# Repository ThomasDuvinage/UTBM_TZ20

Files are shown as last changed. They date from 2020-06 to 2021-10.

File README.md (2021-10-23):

# UTBM TZ20 Project

Welcome to the Github repository of our project !  
It consists in designing, building and programming a full portable console allowing the University of Technology of Belfort-Montbeliard (France) staff to control students attendance at some mandatory events.  
This project involves Raspberry Pi programming through Python, 3D printing, and electronics.
This repository contains all documents related to the project.

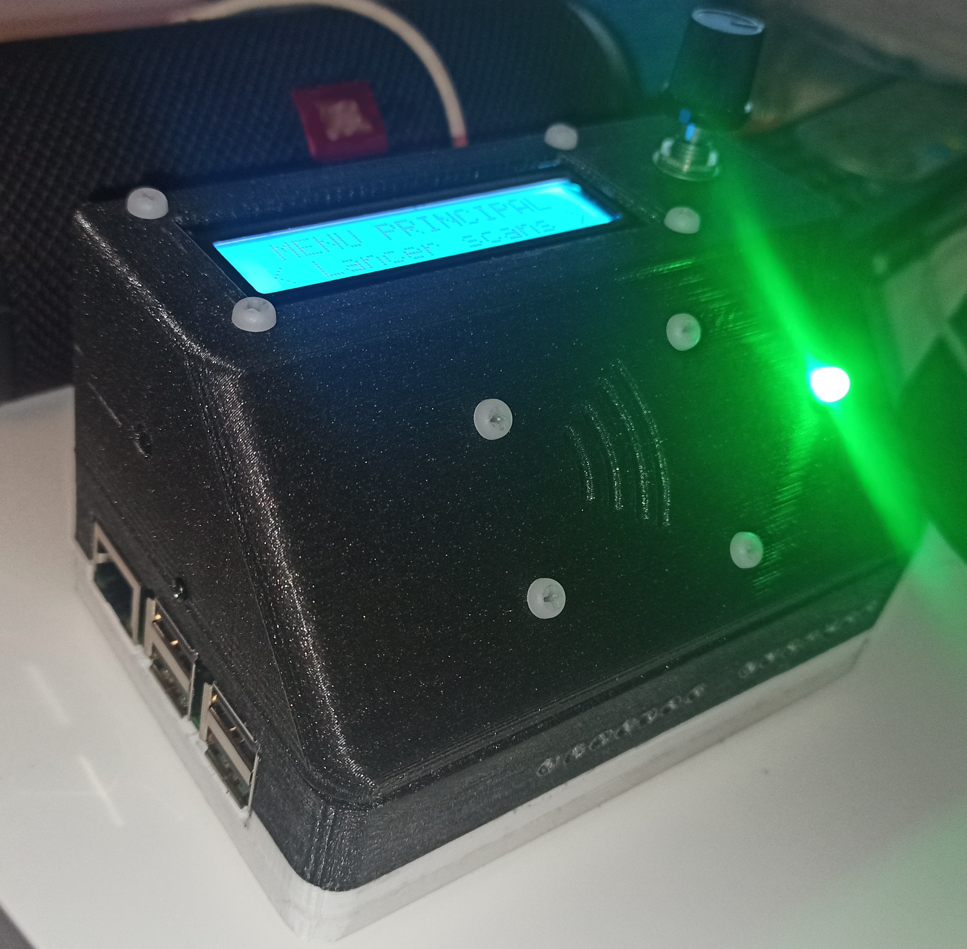
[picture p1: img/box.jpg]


## Useful links : ##

| Description | URL | We used it for : |
|---|---|---|
| RC522 wiring guide | [Click here](https://pimylifeup.com/raspberry-pi-rfid-rc522/) | Wiring RC522 module to the Raspberry Pi. For programming, refer to the line below |
| RC522 python class | [Click here](https://github.com/danjperron/MFRC522-python) | Programming the Raspberry Pi for controlling the RC522 module, especially to read 7 bytes UIDs |
| Git handling from bash terminal | [Click here](https://medium.com/@panjeh/makefile-git-add-commit-push-github-all-in-one-command-9dcf76220f48 )  | Remind us how to handle a git repo from bash terminal |
| Change I2C pins on Raspberry Pi | [Click here](https://raspberrypi.stackexchange.com/questions/88149/change-i2c-pins-on-raspberry-pi) | Opening a second I2C channel on the Raspberry Pi |
| Python class for I2C enabled LCD screens | [Click here](https://www.raspberrypi-spy.co.uk/2015/05/using-an-i2c-enabled-lcd-screen-with-the-raspberry-pi/) | Controlling the 16x2 I2C driven LCD screen through Python |
| Fan controlling from Raspberry Pi | [Click here](https://howchoo.com/g/ote2mjkzzta/control-raspberry-pi-fan-temperature-python) | Wiring and controlling a 5v fan to cool down Raspberry Pi CPU |
| Guide to run python script at Raspi startup | [Click here](https://www.dexterindustries.com/howto/run-a-program-on-your-raspberry-pi-at-startup/#systemd) | Creating a systemd service to run a Python script that reads CPU temp and controls the fan through an hysteresis |
| Guide for using a DS1302 RTC Module with a Raspberry Pi | [Click here](https://github.com/sourceperl/rpi.rtc) | Using an RTC DS1302 module to ensure a non-volatile time management |
| Tutorial about using a config.ini file with Python | [Click here](https://pymotw.com/2/ConfigParser/) | Storing user settings as non-volatile variables |
| Forum about dismounting USB drive from Python | [Click here](https://www.raspberrypi.org/forums/viewtopic.php?t=198250) | Safe ejecting USB keys after importations and exportations

## Hardware (3D printing and electronics) ##
=======
Go to [hardware](hardware/README.md) to see an electronic schematic and our 3D model of the case.

## Installation ##
### By burning TZ20.img to an empty SD card (recommended) ###
>>>>>>> eb0ae4555269eb2e0d8dc44ecf4f938724aca84b

### By cloning this repository ###
Please follow the instructions below to proceed software installation :
1. Make sure wiring is correct (see section *Electronics* above)
2. Download and flash Raspbian or Minibian (command-line only) to an empty SD card (see [here](https://www.raspberrypi.org/documentation/installation/installing-images/))
3. Make sure your default user is named "pi" by opening a terminal (Ctrl + Alt + T) and typing
```
whoami
```
4. Clone this repository to */home/pi* :
```
git clone https://github.com/totordudu/UTBM_TZ20.git
```
5. Enable SPI and I2C interfaces via raspi-config wizard :
```
sudo raspi-config  
```
   * Using your keyboard arrows and Tab key, navigate to **Interfacing Options** and then **I2C**, then confirm
   * Repeat the same operation for **SPI** interface

5.1 Set TimeZone Localisation 
```
sudo raspi-config  
Localisation Option
Change TimeZone
Set to Paris
sudo reboot now
```

6. Run install.sh from the new folder with sudo privileges (you must type your password, by default its *raspberry*) :
```
cd /home/pi/UTBM_TZ20/
sudo chmod +x install.sh
sudo ./install.sh
```
7. Check that *script/main.py* has *-rwxrwxrwx* permissions :
```
ls -l /home/pi/UTBM_TZ20/script/main.py
```
* Otherwise, give those permissions :
    ```
    sudo chmod 777 /home/pi/UTBM_TZ20/script/main.py
    ```

8. Then the script main.py should normally run by typing the following command : 
```
/usr/bin/python /home/pi/UTBM_TZ20/script/main.py
```

9. Restart your raspberry, and *main.py* should automatically start
```
sudo reboot now
```

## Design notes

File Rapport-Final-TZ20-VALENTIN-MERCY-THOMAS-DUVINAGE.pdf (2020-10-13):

# Projet TZ20 Boîtier de contrôle de présence des étudiants

## Rapport final

Etudiants : Valentin Mercy / Thomas Duvinage

Enseignant suiveur : Alexis Flesch

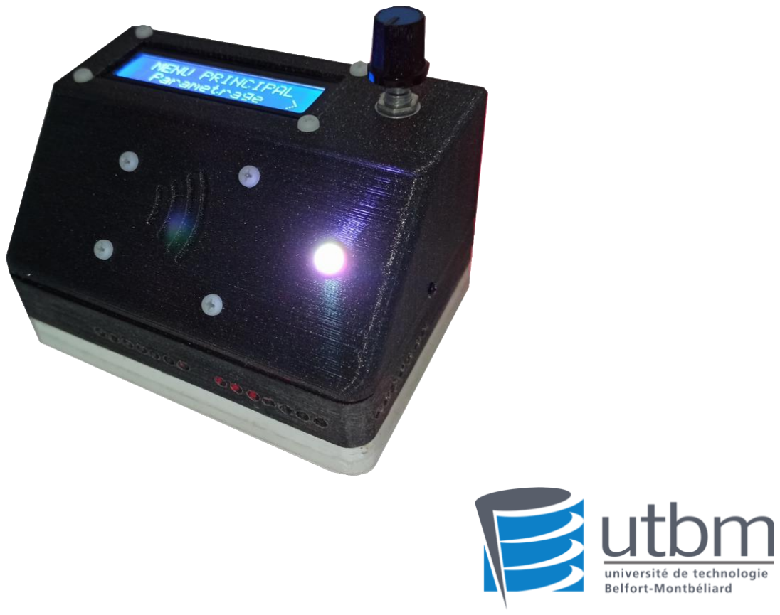
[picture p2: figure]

Valentin Mercy – Thomas Duvinage | Semestre P20 | Page 2/17

Table des matières

Introduction

Ce rapport vient faire suite au rapport intermédiaire rendu au milieu du semestre. Il présentera l’ensemble des travaux réalisés par Thomas Duvinage et Valentin Mercy dans le cadre de l’unité de valeur TZ20 intitulée « Travaux de laboratoire », au printemps 2020, pour le projet de conception et fabrication d’un boîtier de contrôle de présence des étudiants de l’Université de Technologie de Belfort-Montbéliard suivi par M. Alexis Flesch.
Ce rapport est accompagné des documents suivants :
- La présentation utilisée pour la soutenance finale (PDF)
- Le mode d’emploi du boîtier (PDF)
- Le schéma électronique du boîtier (PDF)
- Un modèle de liste des étudiants à importer dans le boîtier (CSV)

Description du projet

Chaque année, plusieurs centaines d’étudiants rentrent à l’Université de Technologie de Belfort-Montbéliard. Un des passages obligatoires pour tous les étudiants de première année est la formation sécurité (il s’agit d’un exemple de ce qui sera dorénavant désigné par le terme « événement ») avant le premier départ en stage. Pour s’assurer que tous les étudiants ont participé à cette formation, l’UTBM a mis en place un système d’émargement informatisé.

Ce système actuel est constitué d’un lecteur RFID¹ USB qui permet aux étudiants de badger avec leur carte étudiante. Celui-ci est relié à un ordinateur portable qui enregistre l’UID (Unique Identifier) de chaque carte dans un fichier CSV²

Après chaque événement, la secrétaire du Tronc Commun UTBM et/ou ses collègues (qui seront dorénavant désignés par le terme « utilisateur ») respectent une certaine procédure :

1) Emport de l’équipement nécessaire (au moins deux appareils : le PC portable (lourd), le lecteur de cartes, et éventuellement un chargeur)
2) Sur le lieu de l’événement : les étudiants sont contraints de rentrer dans l’amphithéâtre un par un, car ils doivent tous se présenter au lecteur de cartes. Un programme exécuté sur le PC portable enregistre un à un les UID des cartes étudiantes. L’arrêt de l’exécution de ce programme met définitivement fin au contrôle de présence, et le matériel est rangé³ .
3) A la fin de l’événement : connexion de l’ordinateur à un réseau wifi et utilisation d’un second programme pour récupérer les logins⁴ en fonction de l’UID de chaque carte.
4) Récupération auprès du service informatique (DSI) du fichier regroupant les informations d’identité des étudiants censés être présents lors de la formation. Avec ce fichier l’utilisateur extrait les noms et prénoms attachés au login. Cela génère deux fichiers : un premier constituant la liste des présents et l’autre la liste des absents.
5) Pour les étudiants qui n’ont pas badgé mais qui ont été signalés présents grâce à l’émargement manuscrit, ils sont retirés manuellement de la liste des absents.

1 RFID = Radio-Frequency Identification (wikipedia.fr, 2020)
2 CSV = Comma Separated Values. Il s’agit d’un fichier texte contenant des chaînes de caractères séparées par des virgules.
3 Ainsi, les étudiants qui se présentent en retard sont listés de façon manuscrite, et retirés un à un de la liste des absents de retour au bureau.
4
Les logins sont des chaînes de caractères courtes qui identifient chaque étudiant de l’UTBM de manière unique.

De plus, en fonction de l’endroit où il est situé, l’utilisateur n’a pas forcément la possibilité de brancher l’ordinateur à une prise électrique. Un autre problème vient de la fiabilité comme nous l’a fait remarquer Madame Cagnon (actuelle secrétaire du Tronc Commun) :
« Nous ne sommes pas sûrs que tous les étudiants aient bien été enregistrés (pas de signal sonore ou de diode lumineuse). Nous devons faire trop de manipulations pour extraire la liste des étudiants. »

Ainsi l’objectif de ce projet est d’automatiser ce processus afin de soulager les utilisateurs et les étudiants, en construisant un boîtier portable et léger intégrant tous les périphériques nécessaires au contrôle de présence. Cela permettra à terme de gagner en efficacité, en temps et de s’affranchir d’éventuelles erreurs de manipulations. Afin de supprimer les files d’attentes (dont la taille excède parfois les 200 étudiants), le boîtier devra pouvoir circuler d’étudiant en étudiant pour un contrôle ultérieur à leur installation dans l’amphithéâtre.

Pour cela le système doit avoir les caractéristiques suivantes :
- Être compact
- Composé d’un seul boîtier portable
- Pas de fils extérieurs
- Être autonome en énergie pour une durée d’au moins 1 heure
- Être rechargeable
- Être simple d’utilisation : limiter la manipulation du boitier au strict nécessaire
- Lire et générer des fichiers compatibles avec Excel
- Respecter le RGPD⁵
- Être capable d’émettre des signaux lumineux et sonore
- Limiter les interactions avec la DSI⁶
- Être inviolable et inextinguible par les étudiants dont on contrôle la présence
- Pouvoir communiquer avec une clé USB (en lecture et en écriture)
- Distinguer les « faux présents » (étudiants qui se présentent alors qu’ils ne sont pas invités à l’événement) des présents
- Être capable de fusionner les résultats d’un contrôle de présence à un autre contrôle réalisé sur un deuxième boîtier identique, dans le cas où l’on souhaiterait procéder à deux contrôles de présence pour un même événement afin, par exemple, de permettre une installation des étudiants plus rapide

Analyse fonctionnelle

Pour exprimer plus clairement le besoin du secrétariat, nous l’avons représenté sur un diagramme bête à cornes :

5 RGPD = Règlement Général sur la Protection des Données 6 DSI = Direction des Services Informatiques (à l’UTBM)

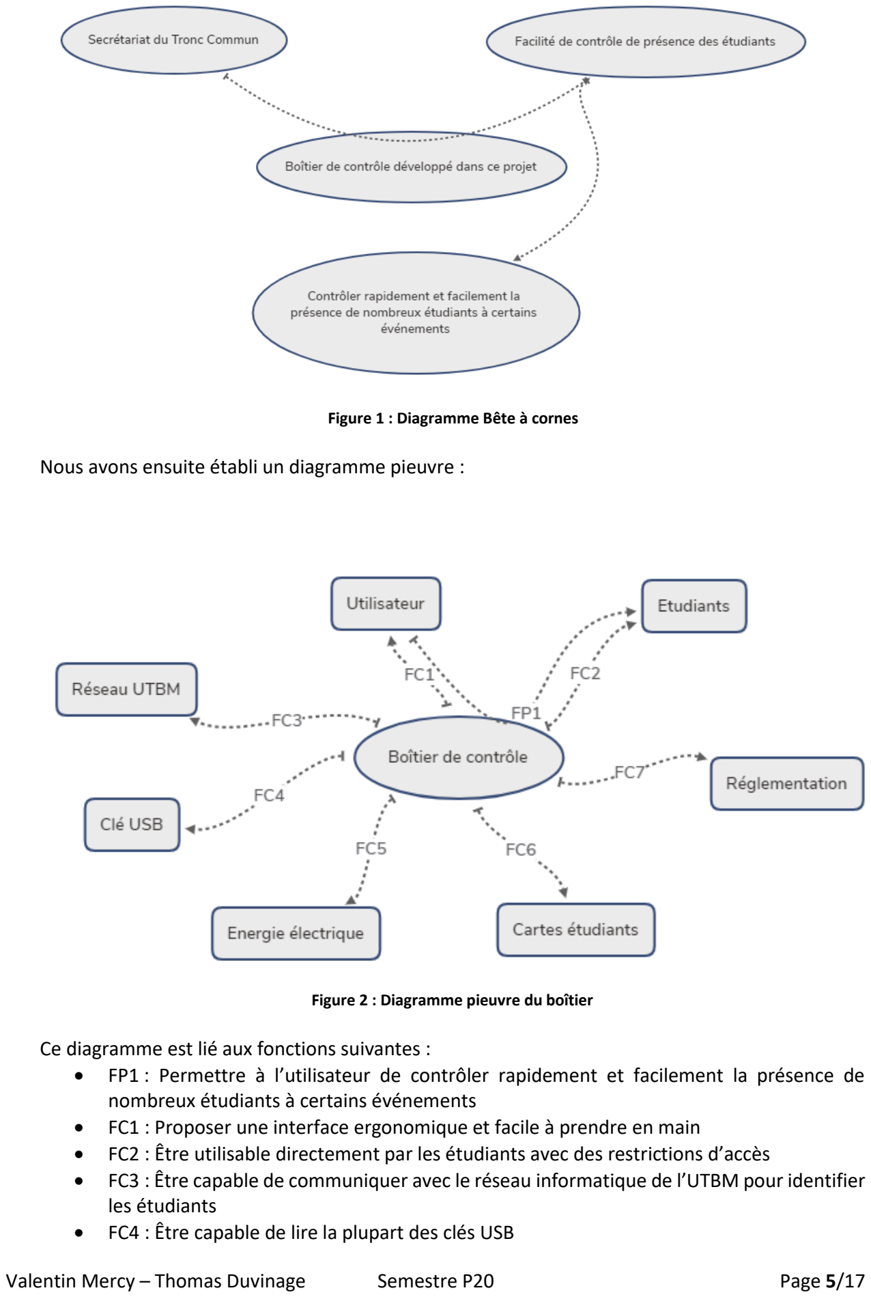
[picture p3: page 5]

Nous avons ensuite établi un diagramme pieuvre :

Figure 2 : Diagramme pieuvre du boîtier

Ce diagramme est lié aux fonctions suivantes :
- FP1 : Permettre à l’utilisateur de contrôler rapidement et facilement la présence de nombreux étudiants à certains événements
- FC1 : Proposer une interface ergonomique et facile à prendre en main
- FC2 : Être utilisable directement par les étudiants avec des restrictions d’accès
- FC3 : Être capable de communiquer avec le réseau informatique de l’UTBM pour identifier les étudiants
- FC4 : Être capable de lire la plupart des clés USB

Figure 1 : Diagramme Bête à cornes

- FC5 : Être autonome en énergie pendant la durée d’un contrôle (au moins une demi-heure)
- FC6 : Être capable de lire les cartes étudiants UTBM
- FC7 : Respecter la réglementation (respect de la vie privée)

Les composants nécessaires

Pour la réalisation de ce projet nous avons besoin de quelques composants électroniques classiques (la plupart étant disponibles préconditionnés en modules) ainsi que de certains éléments de fixation. Vous trouverez dans le tableau ci-dessous la description de l’ensemble des composants ainsi qu’un budget matériel estimatif pour le projet. Il faut également prévoir quelques consommables habituels, spécifiés en rouge dans le tableau.

Liste du matériel - Prix total HT : 86 €
Désignation | Catégorie | Référence | Caractéristiques | Qté | Exemple
URL | Prix HT | Fournisseur | Prix total HT
Raspberry Pi | Eléctronique | 3B+ | Modèle 3B+ ou 4 | 1 | Cliquer ici (https://www.gotronic.fr/art-carte-raspberry-pi-3-b-27826.htm) | 36,63 € | Gotronic | 36,63 €
Ventilateur | Eléctronique | | 30*30*10mm – 5V | 1 | Cliquer ici (https://www.gotronic.fr/art-ventilateur-compatible-pi-29290.htm) | 8,29 € | Gotronic | 8,29 €
Ecran LCD + interface I2C | Eléctronique | | 16x2 – avec module I2C | 1 | Cliquer ici (https://www.gotronic.fr/art-afficheur-lcd-i2c-2x16-caracteres-25650.htm) | 8,25 € | Gotronic | 8,25 €
Alimentation CC | Eléctronique | PS910 | 9V 1A | 1 | Cliquer ici (https://www.gotronic.fr/art-adaptateur-coude-ps910-29061.htm) | 7,17 € | Gotronic | 7,17 €
Level shifter | Eléctronique | CYT1076 | Prix pour pack de 10 pièces – 1 suffit | 1 | Cliquer ici (https://www.amazon.fr/Gebildet-3-3V-5V-Channels-Converter-Bi-Directional/dp/B07RY15XMJ?__mk_fr_FR=Å%20MÅŽÕÑ) | 5,99 € | Amazon | 5,99 €
Powerbank | Eléctronique | U = 5V, I>=1A | à modifier pour souder deux fils en sortie (pas la place pour une prise) | 1 | | | | 5,00 €
Module régulateur de tension | Eléctronique | DRF0571 | Tension entrée : 1.25V – 30V | Sortie : 5V | 1 | Cliquer ici (https://www.gotronic.fr/art-regulateur-5-vcc-dfr0571-29558.htm) | 3,29 € | Gotronic | 3,29 €
Connecteur GPIO femelle à souder | Consommable | | 40 pins (2*20) | 1 | Cliquer ici (https://www.gotronic.fr/art-connecteur-2x20-broches-he40rpi-28118.htm) | 2,58 € | Gotronic | 2,58 €
Buzzer piezoelectrique | Eléctronique | THDZ | | 1 | Cliquer ici (https://www.gotronic.fr/art-buzzer-sv3-3828.htm) | 2,46 € | Gotronic | 2,46 €

Encodeur
rotatif | Eléctronique | KY40 | Bouton intégré | 1

Cliquer
ici (https://www.gotronic.fr/art-module-encodeur-rotatif-gt055-28502.htm)

1,83

€ | Gotronic | 1,83 €
Module RTC | Eléctronique | Module à base de DS1302 | Prix pour pack de 5 pièces – 1 suffit | 1 | Cliquer ici (https://www.amazon.fr/SODIAL-DS1302-Module-Horloge-bouton/dp/B00PXVAKJW?__mk_fr_FR=ÅMÅŽÕÑ) | 1,39 € | Amazon | 1,39 €
Transistor NPN | Eléctronique | 2N2222 | hauteur >=6mm | 1 | Cliquer ici (https://www.gotronic.fr/art-transistor-2n2222a-to92-1539.htm) | 0,25 € | Gotronic | 0,25 €
Fixation LED | Mécanique | | pour LED 5mm | 1 | Cliquer ici (https://www.gotronic.fr/art-clip-5-mm-clip5-2140.htm) | 0,17 € | Gotronic | 0,17 €
Bouton 6x6mm | Eléctronique | KRS0610 | hauteur 7mm | 1 | Cliquer ici (https://www.gotronic.fr/art-bp-subminiature-krs0610-4269.htm) | 0,25 € | Gotronic | 0,25 €
Led rouge | Eléctronique | | 3mm | 1 | Cliquer ici (https://www.gotronic.fr/art-led-3-mm-rouge-l934hd-2058.htm) | 0,13 € | Gotronic | 0,13 €
IRF7319 | Eléctronique | IRF7319 | Composant à monter en surface | 1 | Cliquer ici (https://www.digikey.com/product-detail/en/infineon-technologies/IRF7319TRPBF/IRF7319PBFCT-ND/827930) | 0,83 € | Digikey | 0,83 €
MCP3001 | Eléctronique | MCP3001 | Convertisseur analogique numérique | 1 | Cliquer ici (https://www.digikey.fr/product-detail/en/microchip-technology/MCP3001-I-P/MCP3001-I-P-ND/319407) | 1,51 € | Digikey | 1,51 €
Entretoises taraudées | Mécanique | | M3*6+6 – Nylon de préférence (pour fixations isolées) | 8 | | | | 0,00 €
Vis | Mécanique | | M3*6 | 14 | | | | 0,00 €
Résistances 1/4W | Consommable | | 1*680 R, 2*200 R,1*250 R, 1*500 R, 2*300K | 5 | | | | 0,00 €
Fil électrique souple, multibrin, diam 0,3 | Consommable | 30AWG | Rouge – Noir – Bleu – Vert – Jaune | 5 | | | | 0,00 €
PCB vierge | Consommable | | Carré de 12mm de côté (pour la partie commande du ventilateur) | 1 | | | | 0,00 €

Tableau 1 : Liste du matériel électronique nécessaires pour la réalisation du boitier

L’élément le plus cher utilisé dans le projet est une carte Raspberry Pi 3 modèle B+. Il s’agit d’un nano-ordinateur très performant, de plus en plus utilisé en électronique pour ses ports GPIO⁷ qui

7 GPIO = General Purpose Input Output permettent de communiquer avec une multitude de composants. Ce nano-ordinateur est particulièrement adapté à ce projet car ce dernier implique de la gestion de fichiers, une connexion à Internet filaire, et une communication avec clé USB. Or la Raspberry Pi 3 embarque déjà des ports USB, une prise Ethernet et, en tant que nano-ordinateur exécutant un système d’exploitation basé sur Linux, a déjà tout ce qu’il faut pour manipuler simplement des fichiers en lignes de commandes.
Nous aurions pu nous tourner vers une solution moins gourmande en énergie (type Arduino) mais il aurait alors fallu rajouter tous les modules nécessaires à nos communications. Finalement, le projet serait donc revenu bien plus cher et les performances auraient été très réduites (l’Arduino n’étant pas capable, par exemple, de gérer plusieurs processus en simultané, ce que la Raspberry sait faire).

En plus des composants électroniques, un accès à un FabLab ou un atelier est recommandé, dans la mesure où la réalisation du boîtier nécessite un accès aux machines suivantes :

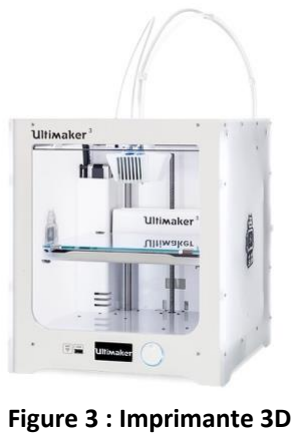
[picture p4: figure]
Figure 3 : Imprimante 3D

- Imprimante 3D (min 100x100x150mm de volume
imprimable)

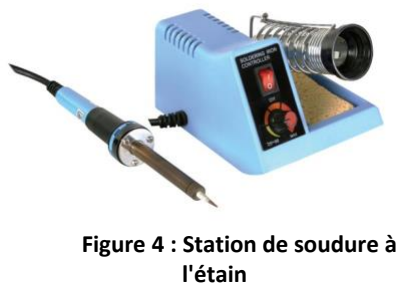
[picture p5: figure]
Figure 4 : Station de soudure à l'étain

- Fer à souder

Schéma électronique

Voici le schéma électronique final du boîtier (celui-ci a été réalisé avec le logiciel Autodesk Eagle) :

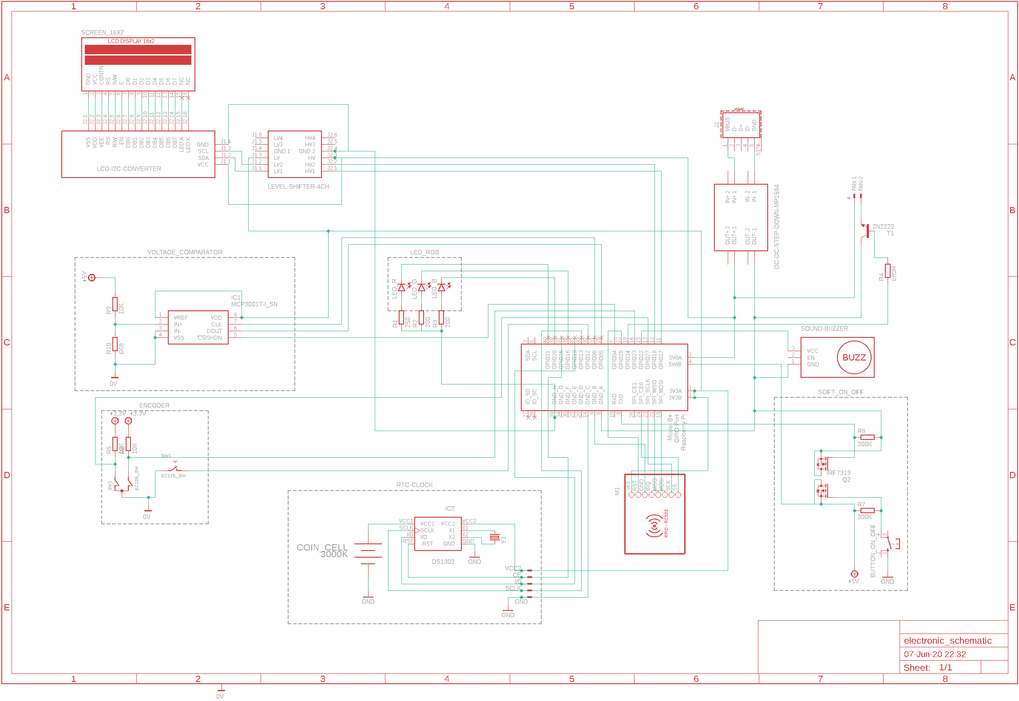
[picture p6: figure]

Figure 5 : Schéma électronique du boîtier

Cette version finale contient les ajouts liés à la détection du niveau de batterie et au circuit de gestion de l’alimentation qui n’étaient pas présents dans le rapport intermédiaire.

Modélisation et impression 3D du boîtier

Une étape importante du projet qui n’a pas été mentionnée dans le rapport intermédiaire a été la modélisation du boîtier. Celle-ci a été faite avec le logiciel Fusion 360. Voici le résultat de notre modélisation (téléchargeable sur notre dépôt Git (https://github.com/totordudu/UTBM_TZ20) ou sur GrabCad) (https://grabcad.com/library/presence-box-1) :

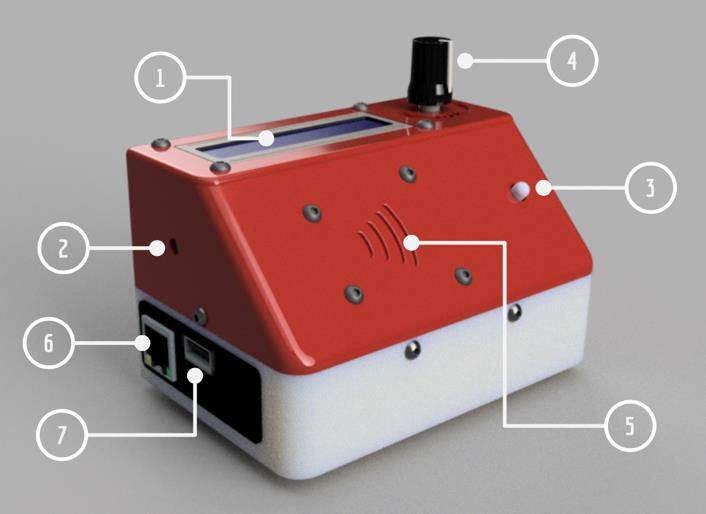
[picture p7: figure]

1. Écran
2. Buzzer
3. LED d’état
4. Sélecteur de menu
5. Zone de scan
6. Port Ethernet
7. Prise USB
8. LED d’allumage
9. Prise d’alimentation
10. Bouton D

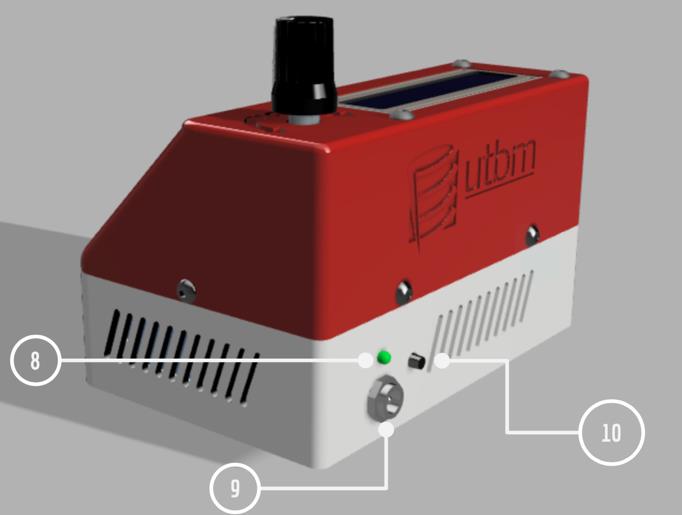
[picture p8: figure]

Le boitier a été imprimé en 3D sur nos machines personnelles.

Organisation de la programmation

L’ensemble du code source qui permet au boîtier de fonctionner a été écrit en langage Python, version 2.7. Il s’agit de la version préinstallée sur Raspbian (principal système d’exploitation utilisé pour les Raspberry Pi). Une partie non-négligeable des connaissances qui nous ont permis d’écrire ce code source (arbres, fonctions récursives) provient de l’UV LO21 de l’UTBM. Afin de se conformer aux bonnes pratiques liées à l’écriture de code, nous avons décidé d’écrire l’ensemble du code en anglais.

Notre dépôt Git

Figure 6 : Modélisation du boitier

Conscients de la quantité de code à fournir (qui, bien qu’optimisée, s’élève finalement à plus de 2000 lignes) et afin d’appréhender la partie programmation informatique du projet dans les meilleures conditions, nous avons créé un dépôt Git sur GitHub. Git est un gestionnaire de versions de code. Un dépôt Git est un dossier contenant principalement du code, stocké sur un serveur, auquel chaque utilisateur authentifié (possédant un compte associé au projet) peut contribuer. Chaque développeur peut alors cloner ce git localement, y apporter les modifications qu’il souhaite, puis procéder à leur indexation (git commit) avant de les publier (git push).
Notre dépôt Git est hébergé à l’URL suivant : https://github.com/totordudu/UTBM_TZ20.
Nous avons également utilisé les fonctionnalités Issues et Project proposées par GitHub, pour notre organisation personnelle :

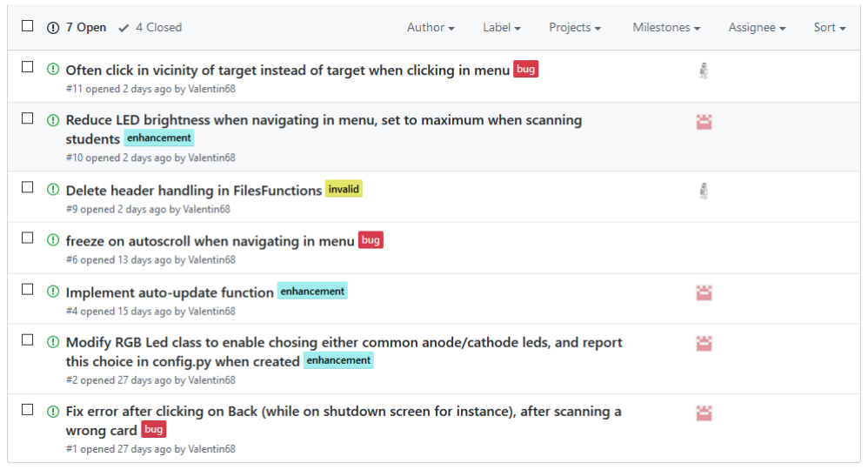
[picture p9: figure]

Depuis le rapport intermédiaire, l’ensemble des Issues importantes ont été traitées. D’autres, moins importantes ou qui auraient nécessité des modifications trop importantes au niveau du code ou de l’électroniques, ont été abandonnées.

Figure 7 : Section "Issues" de notre dépôt Git (au 26/04/2020)

Gestion des fichiers de listes

Pour une meilleure compréhension des différentes opérations de traitement des données (cartes, étudiants, contrôles) réalisées par le boitier, voici un algorigramme :

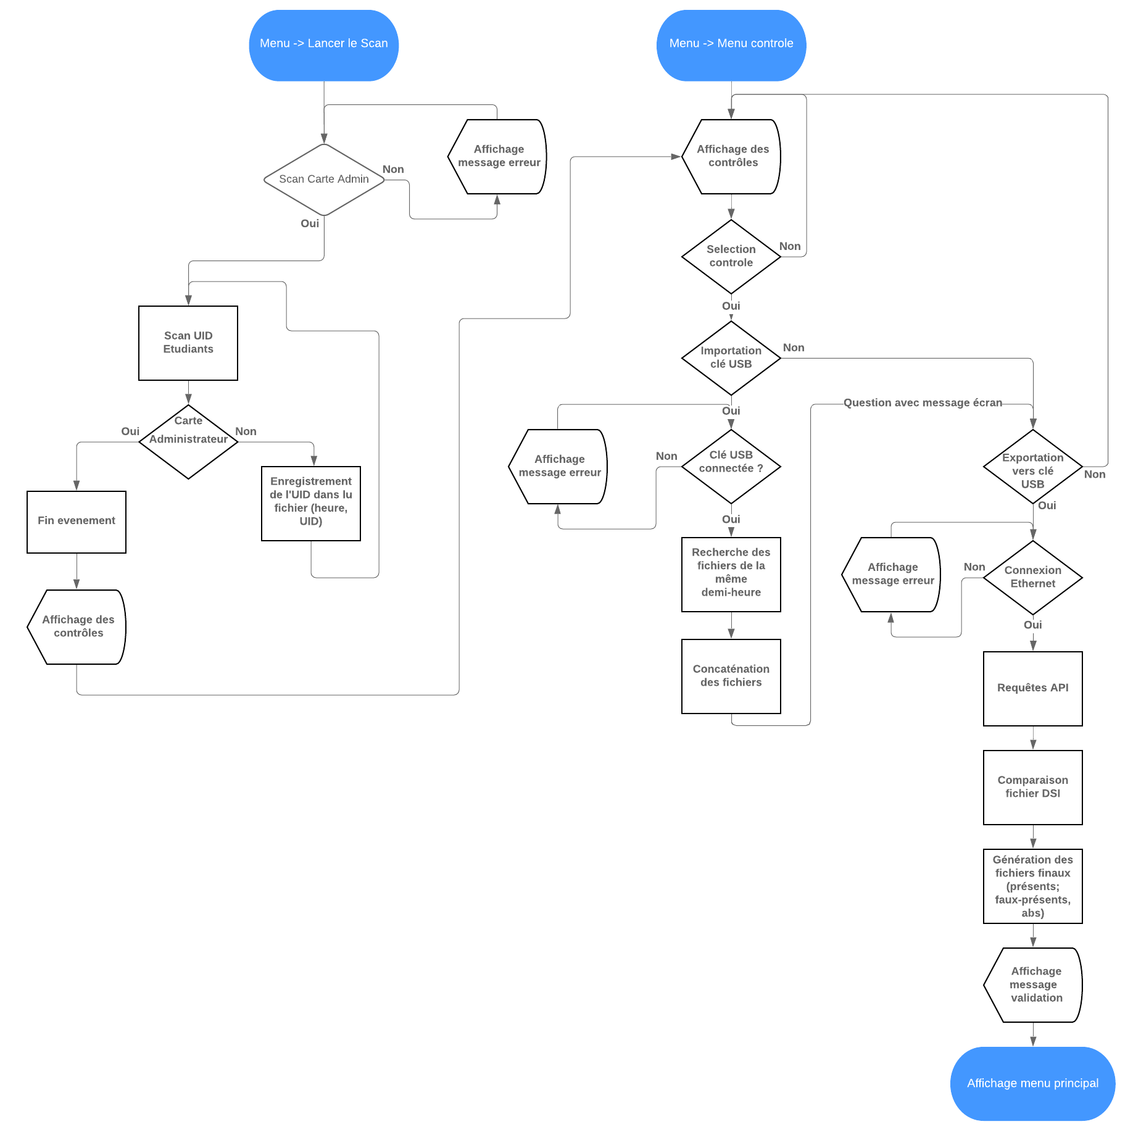
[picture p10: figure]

Librairies utilisées

Plusieurs librairies Python ont été utilisées dans ce projet, toutes ont été trouvées sur GitHub :
- lcd_lib nous permet de gérer l’affichage d’informations sur l’écran LCD via l’interface I2C
- pyRPiRTC nous permet de gérer l’horloge externe (RTC⁸
) en lecture et écriture
- treelib nous permet d’accéder à la structure informatique de l’arbre n-aire dans le cadre de notre menu (voir la partie Chemin utilisateur)

8 RTC = Real Time Clock

Figure 8 : Algorigramme de la gestion des fichiers telle qu’implémentée dans le boitier

- GPIO est une librairie spécifique à Raspbian, permettant de gérer les ports GPIO mentionnés précédemment (entrées/sorties)
- MFRC522 nous permet de communiquer avec le module RC522 (module RFID permettant de scanner les cartes étudiantes)
- datetime nous permet d’accéder à la structure informatique éponyme, qui permet la gestion des ensembles date + heure
- subprocess nous permet de déclencher des sous-processus
- os nous permet de faire appel à des commandes système (normalement saisies dans le terminal)
- signal nous permet de capturer des signaux système (dans notre cas, SIGINT pour une interruption par Ctrl+C) pour les dérouter vers des fonctions appelées traitants (handler en anglais)
- requests nous permet d’envoyer des requêtes vers google pour tester la connexion du boîtier à internet
- ConfigParser nous permet de lire et de modifier le fichier de configuration contenant les paramètres du boîtier, pour les garder en mémoire permanente
- sys nous permet d’utiliser la commande exit() pour mettre fin à l’exécution du programme
- pyudev et psutil nous permettent de détecter le branchement d’une clé USB

Nous avons nous-mêmes codé plusieurs classes Python pour gérer certains éléments propres au boîtier :
- buzzer nous permet de jouer des sons prédéfinis (que nous avons nous-mêmes créés) selon la situation dans laquelle se trouve l’utilisateur
- rgb_led nous permet d’afficher les 7 couleurs avec la LED RGB⁹
, qui vient en complément
de l’écran pour guider l’utilisateur dans le menu et les fonctions auxquelles ce dernier lui permet d’accéder
- rotary_encoder permet de gérer l’encodeur rotatif monté en façade supérieur du boîtier, seule entrée de l’IHM¹⁰ mise en place sur le boîtier, à la fois en rotation et au clic.

Chemin utilisateur

Lors de la programmation d’un boîtier dont l’utilisation doit être simplifiée au maximum tout en assurant un maximum de tâches prédéfinies, il est important de bien réfléchir au chemin utilisateur : l’accessibilité aux différentes fonctions doit être épurée, claire et organisée. Pour ce faire, nous avons imaginé un menu sous forme d’arbre. L’arbre est une structure de données très employée en informatique dès qu’il est utile de hiérarchiser des données sous une arborescence. On parle d’arbre binaire (ou Btree) lorsque chaque nœud a 2 fils au plus, ou d’arbre n-aire dans le cas contraire.

9 RGB = Red Green Blue, appliqué à une LED cela signifie qu’elle peut afficher n’importe quelle couleur par synthèse additive de la lumière
10 IHM = Interface Homme/Machine

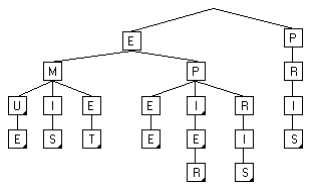
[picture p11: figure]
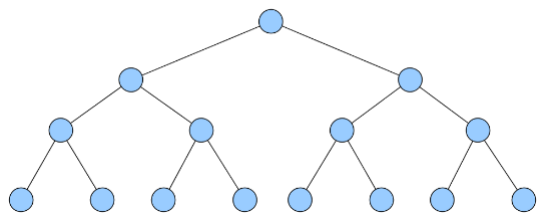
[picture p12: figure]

Dans le cadre de notre menu, nous avons donc choisi d’employer la structure de l’arbre n-aire, prévoyant qu’une entrée de menu permettrait d’accéder à plus de 2 sous-menus. Nous avons essayé d’optimiser ce menu afin de mettre en avant les fonctions qui seront les plus utilisées. Voici l’arbre simplifié de notre menu (l’arbre complet, lui, contient les chaines de caractères à afficher sur l’écran pendant la navigation, la couleur à afficher sur la LED en façade -ici représentée par la couleur du fond du nœud- pour chaque sous-menu ainsi que le nom de la fonction terminale à appeler pour chaque feuille¹¹) :

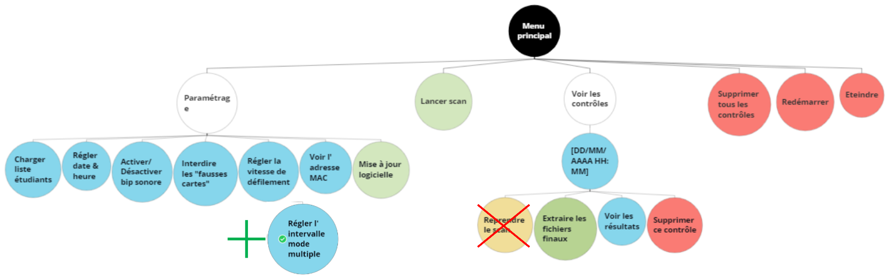
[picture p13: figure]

Depuis le rapport intermédiaire, nous avons supprimé la fonction « Reprendre le scan » accessible depuis le sous-menu « voir les contrôles » car elle est superflue : nous comptions l’implémenter pour permettre à l’administrateur de relancer un scan en cas d’interruption par manque de batterie par exemple. Toutefois, il lui suffirait dans ce cas de lancer le deuxième scan normalement, puis de procéder à une extraction en mode « boitiers multiples » avec fusion pour obtenir de résultat global. Aussi, nous avons ajouté la fonction « Régler l’intervalle du mode multiple » qui permet d’ajuster l’intervalle de temps maximum dans lequel deux contrôles (l’un sur le boîtier, l’autre déjà extrait sur la clé) seront considérés comme similaires et sujets à une fusion des résultats. Pour mieux comprendre, lisez la section Extraction et visualisation des résultats.

Précisions supplémentaires

- Un paramètre « Interdire les fausses cartes » apparaît dans l’arbre du menu. Celui-ci permet d’activer ou de désactiver une restriction lors de la phase de scans : lorsqu’elle est

11 Une feuille est un nœud de l’arbre qui n’a aucun fils (dans notre cas, cela correspond aux fonctions, que l’on désigne ici comme fonctions « terminales », auquel notre menu permet d’accéder)

Figure 10 : Exemple d'arbre binaire

Figure 9 : Exemple d'arbre n-aire

Figure 11 : Arbre simplifié du menu de navigation du boîtier activée, cette restriction empêche les étudiants de scanner d’autres objets compatibles RFID que leur carte étudiante. Toutefois, comme cette restriction se base sur le format des UID de cartes (format spécifique au fournisseur de l’UTBM), nous avons pensé qu’il pourrait être utile de permettre à l’utilisateur de lever cette restriction en cas de changement de fournisseur par exemple, ou bien s’il souhaite contrôler un jour la présence de personnes ne possédant pas de carte UTBM.
- Un paramètre « Voir l’adresse MAC » permet à l’utilisateur de connaître facilement l’adresse physique de la Raspberry. En effet, il est important de la connaître puisqu’elle doit être ajoutée par la DSI à la liste blanche des équipements autorisés à accéder au réseau filaire. Cette autorisation lui sera indispensable pour pouvoir utiliser l’API fournie par la DSI permettant de connaître les propriétaires des cartes étudiantes.
- Un paramètre « mise à jour logicielle » permet à l’utilisateur de mettre à jour notre programme automatiquement. Cela sera utile dans le futur si des bugs que nous n’aurions pas anticipés surviennent après un certain nombre d’utilisations
- Dans la section « Voir contrôles », les différents contrôles auxquels il est possible d’accéder sont identifiés par leur date de création au format DD/MM/AAAA HH:MM.
- En dernière position de chaque sous-menu, une option « RETOUR » permet de remonter au niveau supérieur.

Finalisation du projet

Cette partie présente les étapes de finalisation du projet qui ont été mises en œuvre depuis la rédaction du rapport intermédiaire.

Circuit de gestion de l’alimentation

Le principal élément manquant du schéma électronique publié dans notre rapport intermédiaire était la gestion de la batterie. En effet, nous avions soulevé le problème de la gestion de la batterie en faisant l’expérience d’alimenter la Raspberry Pi en la raccordant directement à la sortie de la batterie. Nous avions alors observé un gros défaut, qui constitue non seulement un trouble pouvant endommager la Raspberry sur le long terme, mais également une entrave à l’ergonomie d’utilisation attendue pour ce boitier : la Raspberry étant toujours alimentée (même si éteinte au niveau logiciel), celle-ci consomme et décharge la batterie jusqu’à son déchargement complet. Pendant ce déchargement, nous avions alors observé un fonctionnement indésirable : la Raspberry tente de s’allumer, puis est coupée en séquence de boot à cause de la chute de tension occasionnée par le démarrage, puis la tension revient à la normale, la Raspberry se rallume, et le cycle recommence jusqu’à épuisement de la batterie.
Nous rappelons par ailleurs qu’en aucun cas la Raspberry ne doit pouvoir être éteinte autrement que par notre programme : les étudiants ne doivent pas pouvoir éteindre le boitier pendant qu’ils scannent leurs cartes, seul l’administrateur peut le décider. C’est pourquoi nous avons intégré le bouton « D » (comme démarrage) dans notre boitier, voir figure 4. (https://github.com/totordudu/UTBM_TZ20)
Nous avons alors établi une liste des fonctions que devrait remplir notre circuit :
- Détection du niveau de batterie et, si sa tension devient insuffisante pour alimenter la Raspberry de manière stable, on lui envoie un signal d’extinction (pour éviter une extinction à chaud, mauvaise pour la carte)
- Coupure de l'alimentation de la Raspberry lorsqu'elle passe en mode "shutdown" (dont l'origine peut être soit le point ci-dessus, soit une extinction volontaire) : il faut donc laisser à la Raspberry le temps de s'éteindre avant d'ouvrir le circuit qui l'alimente
- Réarmement de l'alimentation de la Raspberry par appui sur bouton poussoir. Ce bouton ne doit avoir d'effet que lorsque l'alimentation est coupée et doit alors la rétablir, mais il ne doit pas la couper s'il est actionné et que la Raspberry est alimentée (fonctionnement en sens unique).
- Par ailleurs, le rechargement de la batterie (et donc dépassement du seuil de tension cité plus haut) ne doit pas rallumer la Raspberry, qui ne doit l’être que par un appui sur le bouton D
- Lorsque l'alimentation de la Raspberry est coupée, le circuit lui-même ne doit presque rien consommer (pour éviter d'avoir à recharger la batterie trop souvent)

Après plusieurs recherches infructueuses, nous avons finalement trouvé le circuit suivant (othermod, 2016) appelé Soft On/Off circuit :
Ce circuit fonctionne à partir d’un composant nommé IRF7319 qui n’est autre qu’un assemblage de deux transistors MOSFET, l’un à canal P et l’autre à canal N.
Le transistor à canal P est passant lorsque sa grille (gate) est reliée à la masse, donc lorsqu’on appuie sur le bouton D (Momentary Power Switch). Le second MOSFET, à canal N, permet de maintenir cet état passant : ce dernier n’est passant que lorsque sa grille est à l’état haut, ce qui est le cas lorsque la Raspberry est allumée puisque TXD vaut alors 1. La Raspberry est donc alimentée de manière stable. La seule manière de couper cette alimentation est que TXD passe à l’état bas, ce qui arrive évidemment lorsque la Raspberry est en mode « shutdown » (éteinte logiciellement).

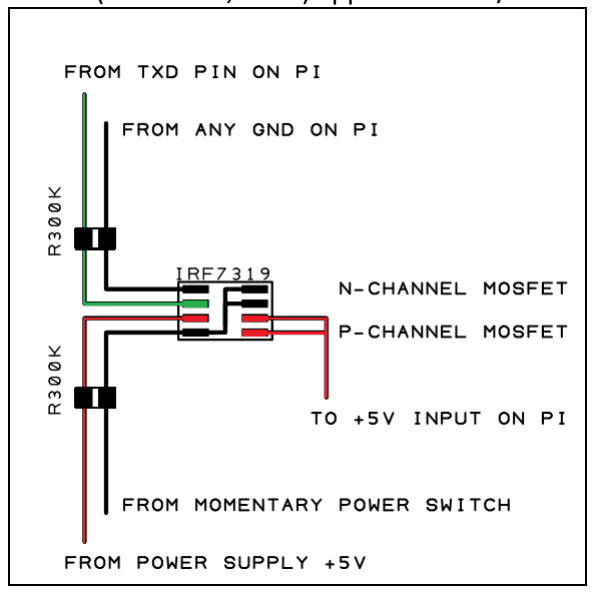
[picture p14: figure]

Ce circuit règle donc une bonne partie du problème, mais il reste la tension de la batterie à gérer : on doit être capables de la lire et de détecter qu’elle passe en dessous d’un certain seuil. La Raspberry Pi ne disposant pas de convertisseur Analogique/Numérique (ADC), nous avons utilisé l’ADC MCP3001 de la très réputée famille des MCP300x et l’avons associé à un pont diviseur dont nous avons judicieusement calculé les valeurs de résistances :
Puisqu’on s’attend à lire une tension maximum de 5v, et qu’on doit retrouver en sortie du pont diviseur une tension de 3v (on garde une marge de sécurité de 0.3v par rapport aux 3.3v de la Raspberry), cela nous donne l’équation suivante (du pont diviseur sans charge avec R1 valant arbitrairement 10K) :
S =

R1
R1+R2

∗ E 3 = 5 ∗

10000
x+10000

=> x ≅ 6K8

Finalement, nous avons donc le circuit de contrôle de tension suivant :

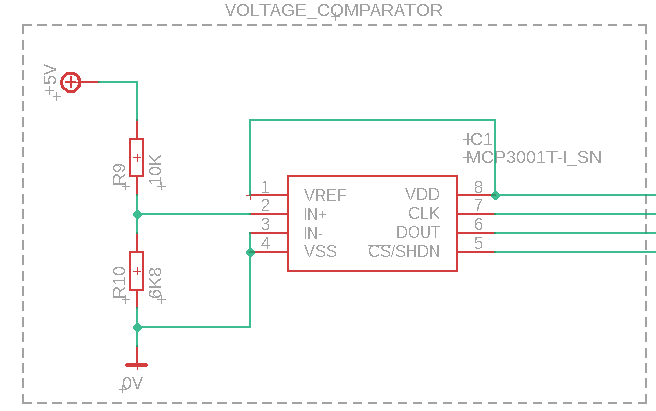
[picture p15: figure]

Figure 12 : Circuit de contrôle de la tension fournie par la batterie

Il nous suffit alors de créer un service sur la Raspberry dont la seule activité sera de lire régulièrement la tension fournie par la batterie, et de déclencher une extinction par sudo shutdown now si cette tension est inférieure à un seuil critique à déterminer.
Ce service (battery.service) et le code Python associé (external_devices/read_voltage.py) sont à retrouver dans le dépôt Git.

Extraction et visualisation des résultats

Concernant l’extraction des fichiers relatifs à un contrôle, nous avons suivi la figure 6 établie pour le rapport intermédiaire au détail près que nous laissons finalement le choix à l’administrateur de rentrer en mode « boitier unique » ou « boitier multiple » suivant qu’il veuille ou non réaliser une fusion par rapport à une extraction précédemment effectuée, dont les résultats sont sur une clé USB branchée à la Raspberry.

Conclusion

Pour conclure, nous sommes très satisfaits du boîtier que nous avons conçu. Nous pensons qu’il répond à tous les critères établis par le secrétariat du Tronc Communs, et attendons leurs premiers tests pour en avoir la confirmation. Mener un tel projet dans une période de confinement n’a pas été chose facile, mais en nous organisant correctement pour travailler efficacement à distance nous avons pu mener le projet à son aboutissement. Celui-ci nous a fait appel à nos connaissances à la fois en mécanique, en électronique et en informatique. Il nous a permis de s’échanger des connaissances et des compétences souvent complémentaires au sein du binôme.

Bibliographie

goobering. 2016. Measuring voltage and current of battery. raspberrypi.stackexchange. [En ligne]
6 | Juillet | 2016. | [Citation | : | 3 | Juin | 2020.]
https://raspberrypi.stackexchange.com/questions/50870/measuring-voltage-and-current-of-battery. othermod. 2016. Raspberry Pi Simple Soft On/Off Circuit. othermod.com. [En ligne] 13 Juillet 2016. [Citation : 03 Juin 2020.] https://othermod.com/raspberry-pi-soft-onoff-circuit/.
wikipedia.fr. 2020. Radio-identification. Wikipedia. [En ligne] 7 avril 2020. [Citation : 20 avril 2020.] https://fr.wikipedia.org/wiki/Radio-identification.

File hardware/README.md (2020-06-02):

## Hardware

### 3D files

To design this box, we used Fusion 360. All the 3D files needed to build this box are available in 3D_prints folder.

All the conception of the box is available on GrabCad at https://grabcad.com/library/presence-box-1

Here are the rendering images of the conception. 

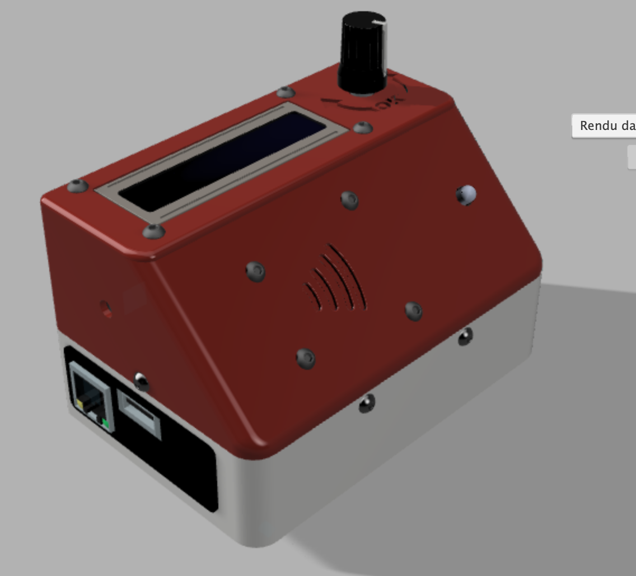
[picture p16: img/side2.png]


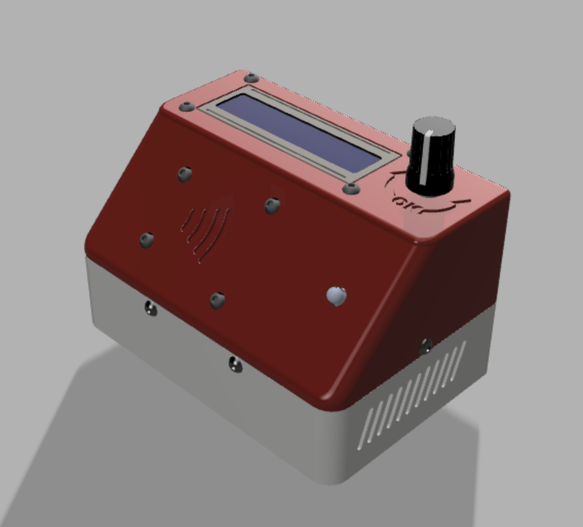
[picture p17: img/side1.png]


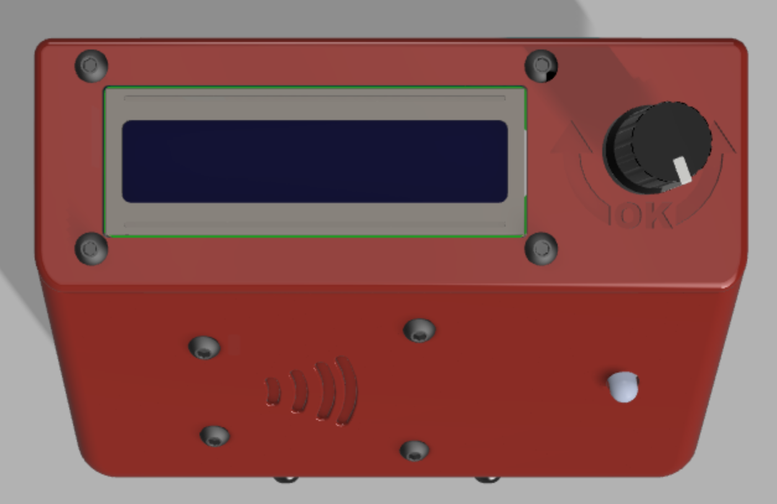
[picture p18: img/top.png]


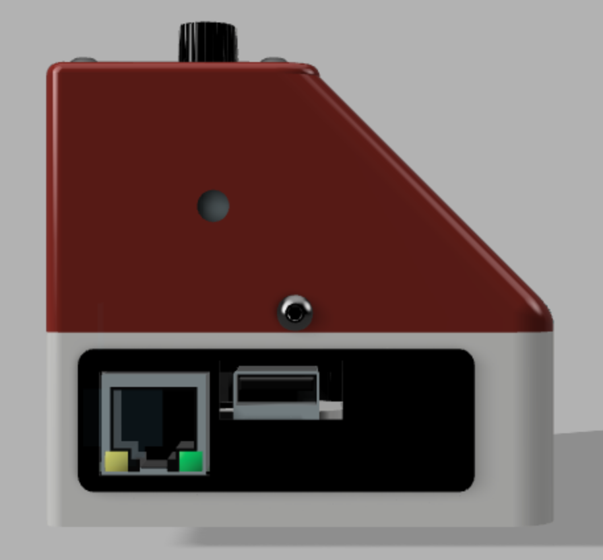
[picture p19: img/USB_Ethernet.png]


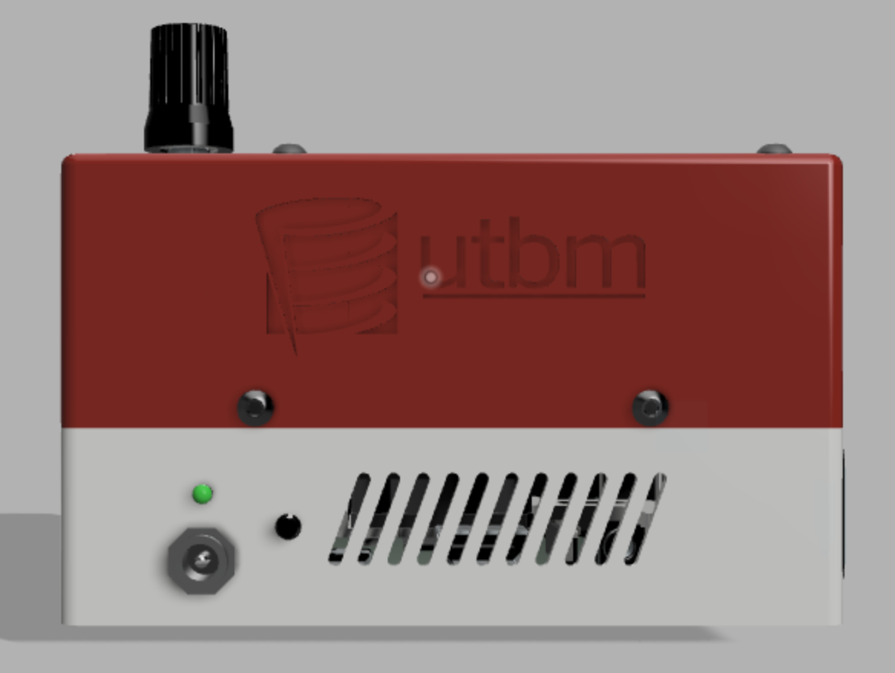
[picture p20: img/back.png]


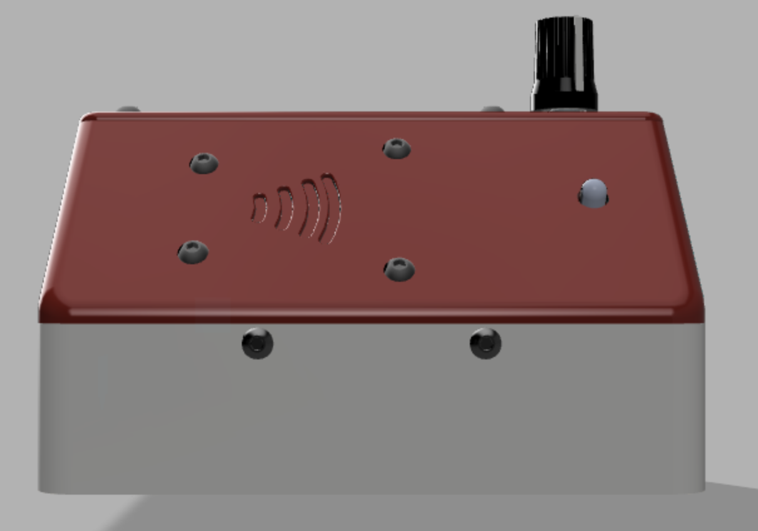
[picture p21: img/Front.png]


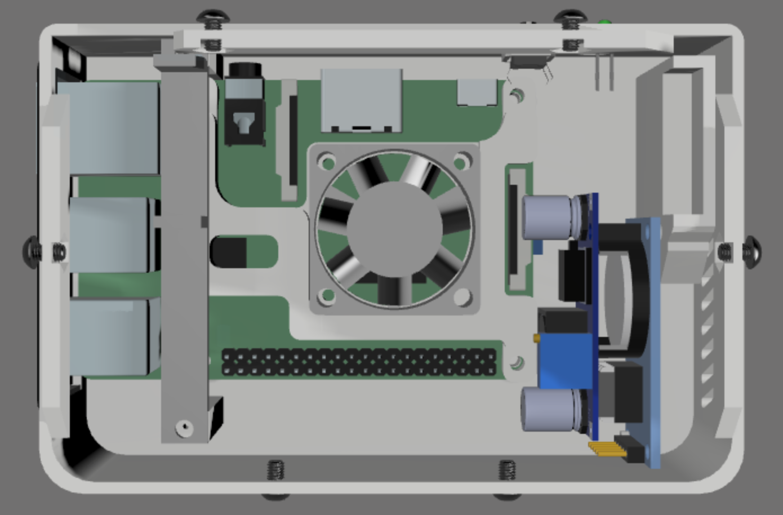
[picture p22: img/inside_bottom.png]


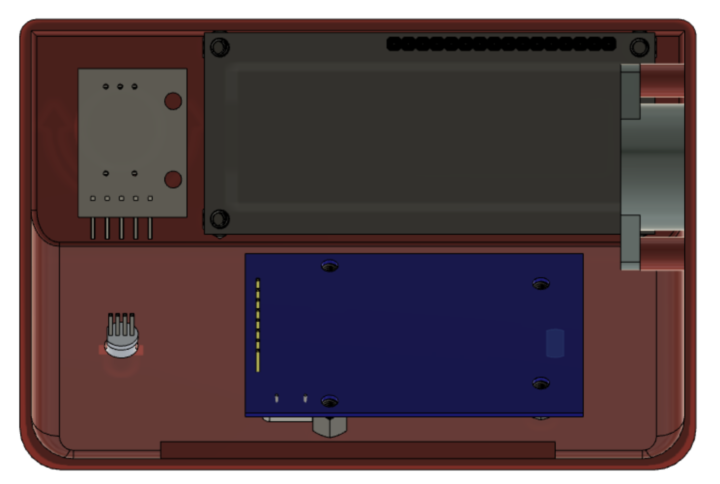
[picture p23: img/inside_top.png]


### Electronic

To create the scheamtic of the project, we used Eagle. Eagle is a very powerful tool made by Autodesk and can be linked with Fusion 360 which is really useful. 

Thanks to this tool, we made the following schematic. If you want more detail about it, a .sch file is available in the electronic folder. 

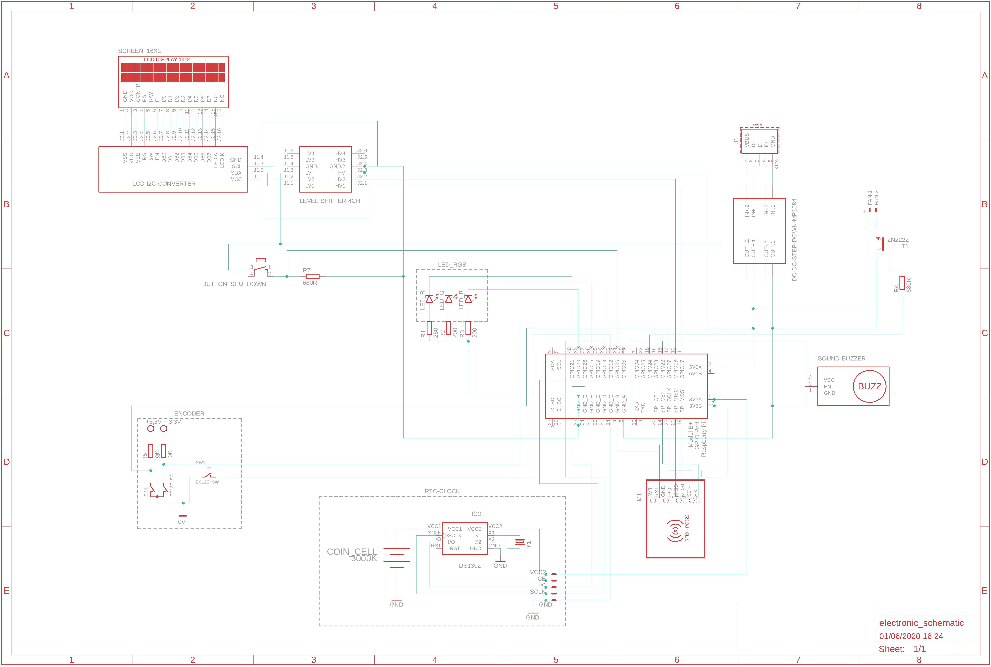
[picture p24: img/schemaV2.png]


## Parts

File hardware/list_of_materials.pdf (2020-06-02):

## UTBM TZ20 – Terminal de contrôle de présence des étudiants

Thomas DUVINAGE

Valentin MERCY

Liste du matériel - Prix total HT : 86,89 € | Sous total
Désignation | Catégorie | Référenc e | Caractéristiqu | Qté | Exemple
es | | URL | Prix HT | Fournisseur Prix total HT
Ventilateur | Eléctronique | | 40*40*10mm – | 1 | | 8,29 € Gotronic | 8,29 € (https://www.gotronic.fr/art-ventilateur-compatible-pi-29290.htm)
Alimentation CC | Eléctronique PS910 | | 9V 1A | 1 | | 7,17 € Gotronic | 7,17 € (https://www.gotronic.fr/art-adaptateur-coude-ps910-29061.htm)
Level shifter | Eléctronique CYT1076 | | Prix pour pack de 10 pièces – | 1 | | 5,99 € Amazon | 5,99 € (https://www.amazon.fr/Gebildet-3-3V-5V-Channels-Converter-Bi-Directional/dp/B07RY15XMJ?__mk_fr_FR=%C3%85)
Connecteur GPIO femelle à souder | Consomma | | 40 pins (2*20) | 1 | | 2,58 € Gotronic | 2,58 € (https://www.gotronic.fr/art-connecteur-2x20-broches-he40rpi-28118.htm)
Buzzer | Eléctronique THDZ | | | 1 | | 2,46 € Gotronic | 2,46 € (https://www.gotronic.fr/art-buzzer-sv3-3828.htm)
Module régulateur de tension | Eléctronique LM2596S | | 1.25V – 30V | 1 https:/ | | 2,08 € Gotronic | 2,08 €
Encodeur rotatif | Eléctronique KY40 | | bouton intégré | 1 | | 1,83 € Gotronic | 1,83 € (https://www.gotronic.fr/art-module-encodeur-rotatif-gt055-28502.htm)
Module RTC | Eléctronique | Module à base de DS1302 | Prix pour pack de 5 pièces – 1 | 1 | | 1,39 € Amazon | 1,39 € (https://www.amazon.fr/SODIAL-DS1302-Module-Horloge-bouton/dp/B00PXVAKJW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)
Embase jack DC Eléctronique SC215 | | | 2,1*5,5mm | 1 | | 1,33 € Gotronic | 1,33 € (https://www.gotronic.fr/art-embase-alim-sc215-123.htm)
Led RGB | Eléctronique | | 5mm - Anode | 1 | | 0,63 € Gotronic | 0,63 € (https://www.gotronic.fr/art-led-rgb-5-mm-led5rvb-2103.htm)
Bouton poussoir | Eléctronique | | | 1 | | 0,33 € Gotronic | 0,33 € (https://www.gotronic.fr/art-bp-subminiature-krs0625-21897.htm)
Transistor NPN | Eléctronique 2N2222 | | hauteur | 1 | | 0,25 € Gotronic | 0,25 € (https://www.gotronic.fr/art-transistor-2n2222a-to92-1539.htm)
Fixation LED | Mécanique | | pour LED 5mm | 1 | | 0,17 € Gotronic | 0,17 € (https://www.gotronic.fr/art-clip-5-mm-clip5-2140.htm)
Led rouge | Eléctronique | | 3mm | 1 | | 0,13 € Gotronic | 0,13 € (https://www.gotronic.fr/art-led-3-mm-rouge-l934hd-2058.htm)
Ecran LCD + interface I2C | Eléctronique | | 16x2 – avec | 1 | | 8,25 € Gotronic | 8,25 € (https://www.gotronic.fr/art-afficheur-lcd-i2c-2x16-caracteres-25650.htm)
Raspberry Pi | Eléctronique 3B+ | | Modèle 3B+ ou | 1 | | 36,63 € Gotronic | 36,63 € (https://www.gotronic.fr/art-carte-raspberry-pi-3-b-27826.htm)
Lecteur RFID | Eléctronique RC522 | | | 1 | | 7,38 € Gotronic | 7,38 € (https://www.gotronic.fr/art-module-rfid-tag-13-56-mhz-gt138-26095.htm)
Entretoises taraudées | Mécanique | | M3*6+6 – Nylon de préférence (pour fixations isolées) | 8 | | | 0,00 €
Vis | Mécanique | | M3*6 | 14 | | | 0,00 €
Résistances 1/4W | Consomma ble | | 1*680ohms, 2*200homs,1*2 50ohms, 1*500ohms | 5 | | | 0,00 €

Lignes barrées : déjà
fournies/commandées
(mais inclues dans total)
5V | https://www.gotronic.fr/art-ventilateur-compatible-pi-29290.htm
| https://www.gotronic.fr/art-adaptateur-coude-ps910-29061.htm
1 suffit | https://www.amazon.fr/Gebildet-3-3V-5V-Channels-Converter-Bi-Directional/dp/B07RY15XMJ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
ble | https://www.gotronic.fr/art-connecteur-2x20-broches-he40rpi-28118.htm
piezoelectrique | https://www.gotronic.fr/art-buzzer-sv3-3828.htm

https://www.gotronic.fr/art-module-encodeur-rotatif-gt055-28502.htm

suffit | https://www.amazon.fr/SODIAL-DS1302-Module-Horloge-bouton/dp/B00PXVAKJW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
| https://www.gotronic.fr/art-embase-alim-sc215-123.htm
commune | https://www.gotronic.fr/art-led-rgb-5-mm-led5rvb-2103.htm
| https://www.gotronic.fr/art-bp-subminiature-krs0625-21897.htm
>=6mm | https://www.gotronic.fr/art-transistor-2n2222a-to92-1539.htm https://www.gotronic.fr/art-clip-5-mm-clip5-2140.htm
| https://www.gotronic.fr/art-led-3-mm-rouge-l934hd-2058.htm
module I2C | https://www.gotronic.fr/art-afficheur-lcd-i2c-2x16-caracteres-25650.htm
4 | https://www.gotronic.fr/art-carte-raspberry-pi-3-b-27826.htm
| https://www.gotronic.fr/art-module-rfid-tag-13-56-mhz-gt138-26095.htm

Powerbank | Eléctronique | U = 5V, I>=1A | à modifier pour souder deux fils en sortie (pas la place pour une prise) | 1 | 0,00 €
Fil électrique souple, multibrin, diam 0,3 | Consomma ble | 30AWG | Rouge – Noir – Bleu – Vert – Jaune | 5 | 0,00 €
PCB vierge | Consomma ble | | Carré de 12mm de côté (pour la partie commande du ventilateur) | /

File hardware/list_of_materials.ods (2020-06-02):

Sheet: List_of_materials
UTBM TZ20 – Terminal de contrôle de présence des étudiants
 |  |  |  |  |  | Thomas | DUVINAGE
 |  | Lignes barrées : déjà fournies/commandées (mais inclues dans total) |  |  |  | Valentin | MERCY
Liste du matériel - Prix total HT : 88,1 € |  |  |  |  |  |  |  | Sous total
Désignation | Catégorie | Référence | Caractéristiques | Qté | Exemple
 |  |  |  |  | URL | Prix HT | Fournisseur | Prix total HT
Ventilateur | Eléctronique |  | 40*40*10mm – 5V | 1 | https://www.gotronic.fr/art-ventilateur-compatible-pi-29290.htm | 8,29 € | Gotronic | 8,29 €
Alimentation CC | Eléctronique | PS910 | 9V 1A | 1 | https://www.gotronic.fr/art-adaptateur-coude-ps910-29061.htm | 7,17 € | Gotronic | 7,17 €
Level shifter | Eléctronique | CYT1076 | Prix pour pack de 10 pièces – 1 suffit | 1 | https://www.amazon.fr/Gebildet-3-3V-5V-Channels-Converter-Bi-Directional/dp/B07RY15XMJ?__mk_fr_FR=%C3%85 M%C3%85%C5%BD%C3%95%C3%91&keywords=level+shifter&qid=1585597052&sr=8-5 | 5,99 € | Amazon | 5,99 €
Connecteur GPIO femelle à souder | Consommable |  | 40 pins (2*20) | 1 | https://www.gotronic.fr/art-connecteur-2x20-broches-he40rpi-28118.htm | 2,58 € | Gotronic | 2,58 €
Buzzer piezoelectrique | Eléctronique | THDZ |  | 1 | https://www.gotronic.fr/art-buzzer-sv3-3828.htm | 2,46 € | Gotronic | 2,46 €
Module régulateur de tension | Eléctronique | DRF0571 | 1.25V – 30V | 1 | https://www.gotronic.fr/art-regulateur-5-vcc-dfr0571-29558.htm | 3,29 € | Gotronic | 3,29 €
Encodeur rotatif | Eléctronique | KY40 | bouton intégré | 1 | https://www.gotronic.fr/art-module-encodeur-rotatif-gt055-28502.htm | 1,83 € | Gotronic | 1,83 €
Module RTC | Eléctronique | Module à base de DS1302 | Prix pour pack de 5 pièces – 1 suffit | 1 | https://www.amazon.fr/SODIAL-DS1302-Module-Horloge-bouton/dp/B00PXVAKJW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 | 1,39 € | Amazon | 1,39 €
Embase jack DC | Eléctronique | SC215 | 2,1*5,5mm | 1 | https://www.gotronic.fr/art-embase-alim-sc215-123.htm | 1,33 € | Gotronic | 1,33 €
Led RGB | Eléctronique |  | 5mm - Anode commune | 1 | https://www.gotronic.fr/art-led-rgb-5-mm-led5rvb-2103.htm | 0,63 € | Gotronic | 0,63 €
Bouton poussoir | Eléctronique |  |  | 1 | https://www.gotronic.fr/art-bp-subminiature-krs0625-21897.htm | 0,33 € | Gotronic | 0,33 €
Transistor NPN | Eléctronique | 2N2222 | hauteur >=6mm | 1 | https://www.gotronic.fr/art-transistor-2n2222a-to92-1539.htm | 0,25 € | Gotronic | 0,25 €
Fixation LED | Mécanique |  | pour LED 5mm | 1 | https://www.gotronic.fr/art-clip-5-mm-clip5-2140.htm | 0,17 € | Gotronic | 0,17 €
Led rouge | Eléctronique |  | 3mm | 1 | https://www.gotronic.fr/art-led-3-mm-rouge-l934hd-2058.htm | 0,13 € | Gotronic | 0,13 €
Ecran LCD + interface I2C | Eléctronique |  | 16x2 – avec module I2C | 1 | https://www.gotronic.fr/art-afficheur-lcd-i2c-2x16-caracteres-25650.htm | 8,25 € | Gotronic | 8,25 €
Raspberry Pi | Eléctronique | 3B+ | Modèle 3B+ ou 4 | 1 | https://www.gotronic.fr/art-carte-raspberry-pi-3-b-27826.htm | 36,63 € | Gotronic | 36,63 €
Lecteur RFID | Eléctronique | RC522 |  | 1 | https://www.gotronic.fr/art-module-rfid-tag-13-56-mhz-gt138-26095.htm | 7,38 € | Gotronic | 7,38 €
Entretoises taraudées | Mécanique |  | M3*6+6 – Nylon de préférence (pour fixations isolées) | 8 |  |  |  | 0,00 €
Vis | Mécanique |  | M3*6 | 14 |  |  |  | 0,00 €
Résistances 1/4W | Consommable |  | 1*680ohms, 2*200homs,1*250ohms, 1*500ohms | 5 |  |  |  | 0,00 €
Powerbank | Eléctronique | U = 5V, I>=1A | à modifier pour souder deux fils en sortie (pas la place pour une prise) | 1 |  |  |  | 0,00 €
Fil électrique souple, multibrin, diam 0,3 | Consommable | 30AWG | Rouge – Noir – Bleu – Vert – Jaune | 5 |  |  |  | 0,00 €
PCB vierge | Consommable |  | Carré de 12mm de côté (pour la partie commande du ventilateur) | /

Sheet: Electronique
Liste du matériel - Prix total HT : 88,1 € |  |  |  |  |  |  |  | Sous total
Désignation | Eléctronique | Référence | Caractéristiques | Qté | Exemple
 |  |  |  |  | URL | Prix HT | Fournisseur | Prix total HT
Ventilateur | Eléctronique |  | 40*40*10mm – 5V | 1 | https://www.gotronic.fr/art-ventilateur-compatible-pi-29290.htm | 8,29 € | Gotronic | 8,29 €
Alimentation CC | Eléctronique | PS910 | 9V 1A | 1 | https://www.gotronic.fr/art-adaptateur-coude-ps910-29061.htm | 7,17 € | Gotronic | 7,17 €
Level shifter | Eléctronique | CYT1076 | Prix pour pack de 10 pièces – 1 suffit | 1 | https://www.amazon.fr/Gebildet-3-3V-5V-Channels-Converter-Bi-Directional/dp/B07RY15XMJ?__mk_fr_FR=%C3%85 M%C3%85%C5%BD%C3%95%C3%91&keywords=level+shifter&qid=1585597052&sr=8-5 | 5,99 € | Amazon | 5,99 €
Connecteur GPIO femelle à souder | Consommable |  | 40 pins (2*20) | 1 | https://www.gotronic.fr/art-connecteur-2x20-broches-he40rpi-28118.htm | 2,58 € | Gotronic | 2,58 €
Buzzer piezoelectrique | Eléctronique | THDZ |  | 1 | https://www.gotronic.fr/art-buzzer-sv3-3828.htm | 2,46 € | Gotronic | 2,46 €
Module régulateur de tension | Eléctronique | DRF0571 | 1.25V – 30V | 1 | https://www.gotronic.fr/art-regulateur-5-vcc-dfr0571-29558.htm | 3,29 € | Gotronic | 3,29 €
Encodeur rotatif | Eléctronique | KY40 | bouton intégré | 1 | https://www.gotronic.fr/art-module-encodeur-rotatif-gt055-28502.htm | 1,83 € | Gotronic | 1,83 €
Module RTC | Eléctronique | Module à base de DS1302 | Prix pour pack de 5 pièces – 1 suffit | 1 | https://www.amazon.fr/SODIAL-DS1302-Module-Horloge-bouton/dp/B00PXVAKJW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 | 1,39 € | Amazon | 1,39 €
Embase jack DC | Eléctronique | SC215 | 2,1*5,5mm | 1 | https://www.gotronic.fr/art-embase-alim-sc215-123.htm | 1,33 € | Gotronic | 1,33 €
Led RGB | Eléctronique |  | 5mm - Anode commune | 1 | https://www.gotronic.fr/art-led-rgb-5-mm-led5rvb-2103.htm | 0,63 € | Gotronic | 0,63 €
Bouton poussoir | Eléctronique |  |  | 1 | https://www.gotronic.fr/art-bp-subminiature-krs0625-21897.htm | 0,33 € | Gotronic | 0,33 €
Transistor NPN | Eléctronique | 2N2222 | hauteur >=6mm | 1 | https://www.gotronic.fr/art-transistor-2n2222a-to92-1539.htm | 0,25 € | Gotronic | 0,25 €
Fixation LED | Mécanique |  | pour LED 5mm | 1 | https://www.gotronic.fr/art-clip-5-mm-clip5-2140.htm | 0,17 € | Gotronic | 0,17 €
Led rouge | Eléctronique |  | 3mm | 1 | https://www.gotronic.fr/art-led-3-mm-rouge-l934hd-2058.htm | 0,13 € | Gotronic | 0,13 €
Ecran LCD + interface I2C | Eléctronique |  | 16x2 – avec module I2C | 1 | https://www.gotronic.fr/art-afficheur-lcd-i2c-2x16-caracteres-25650.htm | 8,25 € | Gotronic | 8,25 €
Raspberry Pi | Eléctronique | 3B+ | Modèle 3B+ ou 4 | 1 | https://www.gotronic.fr/art-carte-raspberry-pi-3-b-27826.htm | 36,63 € | Gotronic | 36,63 €
Lecteur RFID | Eléctronique | RC522 |  | 1 | https://www.gotronic.fr/art-module-rfid-tag-13-56-mhz-gt138-26095.htm | 7,38 € | Gotronic | 7,38 €

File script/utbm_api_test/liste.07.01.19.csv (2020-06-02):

Heure | Id
13h46 | 80543950692404
13h47 | 80545467667504
13h47 | 80570282724004

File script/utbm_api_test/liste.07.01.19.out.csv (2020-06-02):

Heure | Id
13h46 | log1
13h47 | log2
13h47 | log3

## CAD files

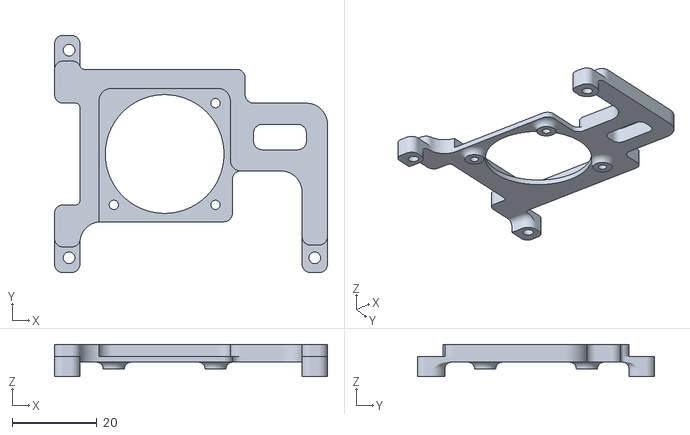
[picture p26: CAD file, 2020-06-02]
hardware/3D_prints/Fan_holder.stl
64.4 x 56.0 x 7.60

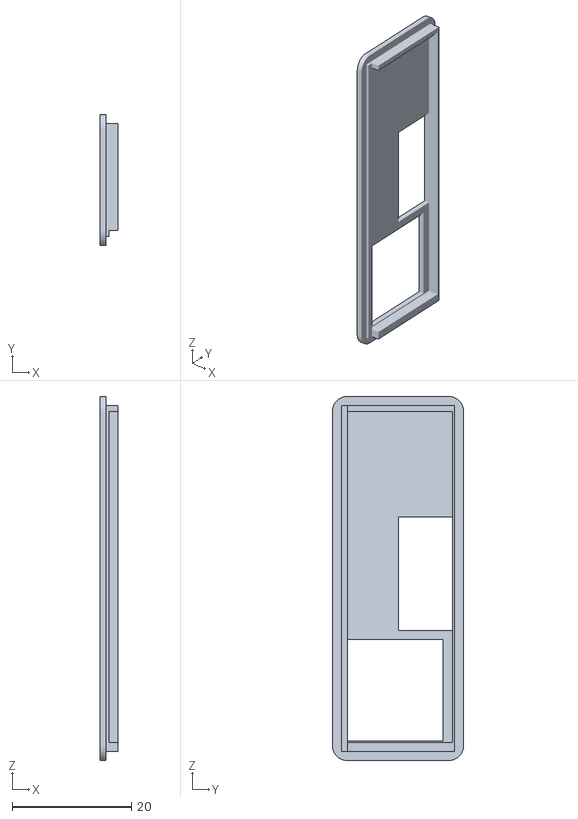
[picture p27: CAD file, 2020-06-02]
hardware/3D_prints/Ports_hidder.stl
3.00 x 22.0 x 61.0

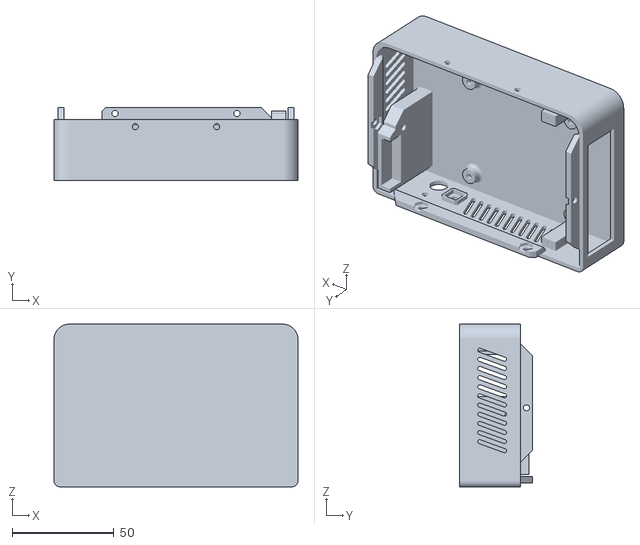
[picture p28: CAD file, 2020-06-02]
hardware/3D_prints/Lower_box.stl
120.0 x 36.0 x 80.0

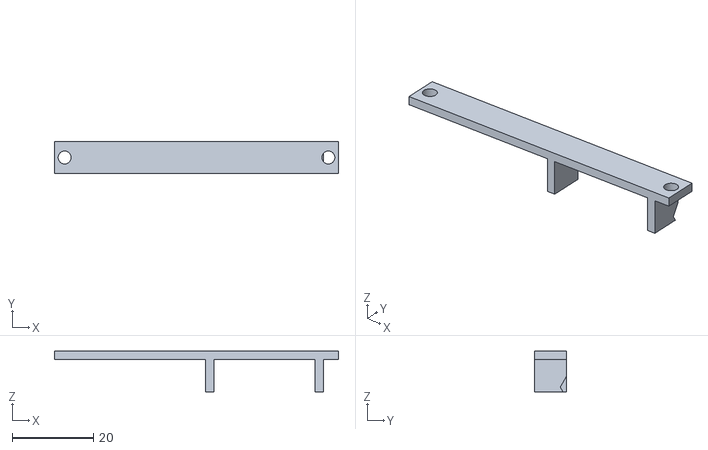
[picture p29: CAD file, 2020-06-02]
hardware/3D_prints/Powerbank_holder.stl
70.1 x 8.00 x 10.0

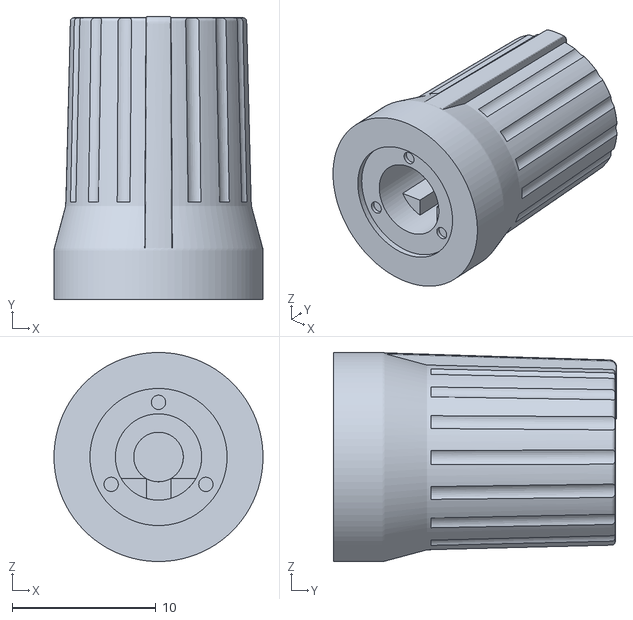
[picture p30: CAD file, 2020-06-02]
hardware/3D_prints/Encoder_cap.stl
14.5 x 19.7 x 14.5

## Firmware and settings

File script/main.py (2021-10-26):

#! /usr/bin/python
'''
 ___      ___ ________  ___       _______   ________   _________  ___  ________   ________  ________     
|\  \    /  /|\   __  \|\  \     |\  ___ \ |\   ___  \|\___   ___\\  \|\   ___  \|\   ____\|\   __  \    
\ \  \  /  / | \  \|\  \ \  \    \ \   __/|\ \  \\ \  \|___ \  \_\ \  \ \  \\ \  \ \  \___|\ \  \|\  \   
 \ \  \/  / / \ \   __  \ \  \    \ \  \_|/_\ \  \\ \  \   \ \  \ \ \  \ \  \\ \  \ \  \____\ \   __  \  
  \ \    / /   \ \  \ \  \ \  \____\ \  \_|\ \ \  \\ \  \   \ \  \ \ \  \ \  \\ \  \ \  ___  \ \  \|\  \ 
   \ \__/ /     \ \__\ \__\ \_______\ \_______\ \__\\ \__\   \ \__\ \ \__\ \__\\ \__\ \_______\ \_______\
    \|__|/       \|__|\|__|\|_______|\|_______|\|__| \|__|    \|__|  \|__|\|__| \|__|\|_______|\|_______|
                                                                                                         
                                                                                                         
                                                                                                         
 _________  ________  _________  ________  ________  ________  ___  ___  ________  ___  ___              
|\___   ___\\   __  \|\___   ___\\   __  \|\   __  \|\   ___ \|\  \|\  \|\   ___ \|\  \|\  \             
\|___ \  \_\ \  \|\  \|___ \  \_\ \  \|\  \ \  \|\  \ \  \_|\ \ \  \\\  \ \  \_|\ \ \  \\\  \            
     \ \  \ \ \  \\\  \   \ \  \ \ \  \\\  \ \   _  _\ \  \ \\ \ \  \\\  \ \  \ \\ \ \  \\\  \           
      \ \  \ \ \  \\\  \   \ \  \ \ \  \\\  \ \  \\  \\ \  \_\\ \ \  \\\  \ \  \_\\ \ \  \\\  \          
       \ \__\ \ \_______\   \ \__\ \ \_______\ \__\\ _\\ \_______\ \_______\ \_______\ \_______\         
        \|__|  \|_______|    \|__|  \|_______|\|__|\|__|\|_______|\|_______|\|_______|\|_______|         
                                                                                                         

Created on March 2020 by valentin.mercy[at]utbm[dot]fr for UTBM TZ20 project : https://github.com/totordudu/UTBM_TZ20
Edited by valentin.mercy[at]utbm[dot]fr and thomas.duvinage[at]utbm[dot]fr

'''
import FilesFunctions.structureConfig as structConfig
import urllib2
import re
from external_devices.lcd_lib import *
from external_devices.buzzer import *
from external_devices.rgb_led import *
from external_devices.rotary_encoder import *
from external_devices.pyRPiRTC import *
import treelib
from RPi import GPIO
from external_devices.MFRC522 import *
import datetime
import subprocess
import os
import requests
from FilesFunctions import *
from ConfigParser import SafeConfigParser
import signal
import sys
""" import pyudev
import psutil """

GPIO.setwarnings(False)

# INITIALIZATION OF INTERNAL OBJECTS
led = Led()
buzz = Buzzer()
encoder = Encoder()

# if True, the program will only accept UTBM-like cards (7 bytes UID beginning by 80 and ending by 04), both for admin and students
acceptUTBMCardsOnly = True
enableStart = True
ScrollSpeed = 65  # in percents
IntervalMulti = datetime.timedelta(0)

ConfigFileName = "/home/pi/UTBM_TZ20/script/mainconfig.ini"
IsInterruptionIntentional = False
FileDatetimeFormat = "%d-%m-%Y-%H-%M-%S"
ConnectionTestUID = "805A42AA825904"
ForceLevel = []
version = 0  # date of last git pull

# INITIALIZATION OF VARIABLES AND EXTERNAL OBJECTS
continue_reading = True
admin_uid = "805A42AA825904"
mylcd = lcd()
mylcd.lcd_clear()
MIFAREReader = MFRC522()
# To use RTC : lecture : datetime = rtc.read_datetime(), ecriture : rtc.write_datetime(dt_write)
rtc = DS1302(clk_pin=13, data_pin=19, ce_pin=26)

# FUNCTIONS ABOUT ADMIN AUTHENTIFICATION AND CARD SCANNING


def RecordAdmin():  # Records the administrator. The administrator will be the only one that can stop scanning procedure and delete controls (individually and all at once)
    led.setColor("m", led)
    mylcd.lcd_clear()
    mylcd.lcd_display_string(" SCANNEZ CARTE", 1)
    mylcd.lcd_display_string(" ADMINISTRATEUR", 2)
    uid = WaitForCard(False)
    while not CheckUIDFormat(uid):
        buzz.error()
        YesNoBackScreen('BADGE INCOHERENT', "r", ['OK'], 'OK')
        led.setColor("m", led)
        mylcd.lcd_clear()
        mylcd.lcd_display_string(" SCANNEZ CARTE", 1)
        mylcd.lcd_display_string(" ADMINISTRATEUR", 2)
        uid = WaitForCard(False)
    buzz.success()
    return uid


def CheckUIDFormat(UID):  # Checks if a card UID corresponds to a UTBM card
    if acceptUTBMCardsOnly:
        if len(UID) == 14 and UID[0:2] == "80" and UID[12:14] == "04":
            return True
        else:
            return False
    else:
        return True


def CheckAdmin():  # Authentificates the administrator before allowing access to sensible functions
    led.setColor("m", led)
    mylcd.lcd_clear()
    mylcd.lcd_display_string(" SCANNEZ CARTE", 1)
    mylcd.lcd_display_string("ADMIN.     >RET<", 2)
    Attempt = WaitForCard(True)
    while(Attempt != admin_uid):
        if(Attempt == -1):  # function has been interrupted by encoder click (user request back level)
            return False
        buzz.error()
        YesNoBackScreen('MAUVAISE CARTE', "r", ['OK'], 'OK')
        led.setColor("m", led)
        mylcd.lcd_clear()
        mylcd.lcd_display_string(" SCANNEZ CARTE", 1)
        mylcd.lcd_display_string("ADMIN.     >RET<", 2)
        Attempt = WaitForCard(True)
        if not CheckUIDFormat(Attempt):
            buzz.error()
            YesNoBackScreen('BADGE INCOHERENT', "r", ['OK'], 'OK')
    buzz.success()
    return True


# Following 3 variables are used to simulate fake cards for development purposes
FoolUIDs = False  # must be False if user has not registered his MAC addresses in dict below

MAC_addresses = {
    'b8:27:eb:b5:93:fd': 'val',  # developper 1
    'b8:27:eb:1f:ce:1b': 'tom'  # developper 2
}

fakeUIDs = {
    'val':
    {
        '805A42AA825904': "805A42AA825904",  # admin one must map to itself
        '805CB8BAA55D04': "80556170911404",
        '805CB8BAA4F704': "80557144006904",
        '805CB8BAA4BE04': "80583632928104",
        '805CB8BAA4FB04': "80561351520504",
        '805CB8BAA4AA04': "80522816482504",
        '805CB8BAA49D04': "80543190596804",
        '805CB8BAA56104': "80550722390004",
        '805CB8BAA4E104': "80525133961304",
        '805CB8BAA4A204': "80557514066004",
        '815CB8BAA42204': "80546189531104"
    },
    'tom':
    {
        '805A42AA825904': "805A42AA825904",  # admin one must map to itself
        '805CB8BAA4AE04': "80556170911404",
        '805CB8BAA48B04': "80557144006904",
        '815CB8BAA40504': "80583632928104",
        '805CB8BAA57004': "80561351520504",
        '805CB8BAA57404': "80522816482504",
        '805CB8BAA58404': "80543190596804",
        '805CB8BAA48704': "80550722390004",
        '805CB8BAA4E504': "80525133961304",
        '815CB8BAA41204': "80557514066004",
        '815CB8BAA40E04': "80546189531104"
    }
}


def uidToString(uid):  # Formats a scanned UID to a clean string
    mystring = ""
    for i in uid:
        mystring = format(i, '02X') + mystring
    return mystring


def WaitForCard(allowClick, timeout=-1):  # Waits for RC-522 to scan a new card with timeout
    end = datetime.datetime.now() + datetime.timedelta(seconds=timeout)
    while continue_reading:
        if allowClick and encoder.isClicked():
            AntiRebound()
            return -1
        if timeout > 0 and datetime.datetime.now() >= end:
            return -1
        # Scan for cards
        (status, TagType) = MIFAREReader.MFRC522_Request(MIFAREReader.PICC_REQIDL)

        # If a card is found
        if status == MIFAREReader.MI_OK:
            print ("Card detected")

            # Get the UID of the card
            (status, uid) = MIFAREReader.MFRC522_SelectTagSN()
            # If we have the UID, continue
            if status == MIFAREReader.MI_OK:
                print("Card read UID: %s" % uidToString(uid))
                if FoolUIDs:
                    try:
                        return fakeUIDs[MAC_addresses[getMAC('eth0')]][uidToString(uid)]
                    except KeyError:
                        print(
                            "Can't fool UID because of unknown MAC or unregistered fake Card")
                        return uidToString(uid)
                else:
                    return uidToString(uid)
            else:
                print("Authentication error")

# FUNCTIONS ABOUT DISPLAY AND NAVIGATION


def CenterOnScreen(string, width):  # Centers given string
    nb_spaces = (width-len(string))/2
    newString = " "*nb_spaces+string+" "*(width-(nb_spaces+len(string)))
    return newString


# Interface that present options to user. options_list array contains 3 characters strings in the following order : yes, no, back
def YesNoBackScreen(line_1, led_state, options_list, defaultOption):
    # implementer avec AUTOSCROLL
    led.setColor(led_state, led)
    mylcd.lcd_clear()
    # mylcd.lcd_display_string(CenterOnScreen(line_1,16),1)
    NbOptions = len(options_list)
    pos = 0
    if(options_list.count(defaultOption) == 1):
        pos = options_list.index(defaultOption)
    if(NbOptions == 0):
        print("ERROR NO OPTION ON YESNOBACK SCREEN")
        return -1
    else:
        while not encoder.isClicked():
            optionStrings = []
            for opt in options_list:
                if options_list.index(opt) == pos:
                    optionStrings.append(CenterOnScreen(">"+opt+"<", 5))
                else:
                    optionStrings.append(CenterOnScreen(opt, 5))
            separator = ""
            line_2 = CenterOnScreen(separator.join(optionStrings), 16)
            mylcd.lcd_display_string(line_2, 2)
            encoder.updateCount()
            old_count = encoder.getCount()
            while not encoder.updateCount():
                if FSAutoScroll(line_1, 1):
                    break
            encoder.updateCount()
            new_count = encoder.getCount()
            if new_count > old_count and pos < (NbOptions-1):
                pos += 1
            elif(new_count < old_count and pos > 0):
                pos -= 1
        AntiRebound()
        return options_list[pos]  # return final choice after encoder click


# Full Screen AutoScroll, has nothing to see with AutoScroll function below
def FSAutoScroll(String, line):
    j = 0
    while(not encoder.isClicked() and not encoder.updateCount()):
        mylcd.lcd_display_string(CenterOnScreen(String[j:j+16], 16), line)
        if(len(String)-j <= 16):
            j = 0
        else:
            j += 1
        if(EncWatchPause(1-float(ScrollSpeed)/100)):
            return True
    if encoder.isClicked():
        AntiRebound()
    return True


# Multi Line Autoscroll : holds autoscroll during a certain amount of time. Can't be interrupted while autoscrolling, but only between two autoscroll steps
def holdScreen(Strings, ledState, sec, ForbidInterruption):
    mylcd.lcd_clear()
    setLedState(ledState)
    deb = datetime.datetime.now()
    while(datetime.datetime.now() < deb+datetime.timedelta(seconds=sec)):
        for i in range(1, 3):
            mylcd.lcd_display_string(CenterOnScreen(Strings[i-1], 16), i)
        for i in range(1, 3):
            j = 0
            while ForbidInterruption:
                mylcd.lcd_display_string(
                    CenterOnScreen(Strings[i-1][j:j+16], 16), i)
                if(len(Strings[i-1])-j < 16):
                    break
                else:
                    j += 1
                time.sleep(1-float(ScrollSpeed)/100)
            while not ForbidInterruption and datetime.datetime.now() < deb+datetime.timedelta(seconds=sec):
                mylcd.lcd_display_string(
                    CenterOnScreen(Strings[i-1][j:j+16], 16), i)
                if(len(Strings[i-1])-j < 16):
                    break
                else:
                    j += 1
                time.sleep(1-float(ScrollSpeed)/100)


# Used to handle screen-size overshoot
def AutoScroll(CenterString, CurrentPosition, nbElements):
    j = 0
    while(not encoder.isClicked() and not encoder.updateCount()):
        if(CurrentPosition == 0):  # left extremity
            mylcd.lcd_display_string(
                "  "+CenterString[j:j+12]+" "*(12-len(CenterString[j:j+12]))+" >", 2)
        elif(CurrentPosition == nbElements-1):  # right extremity
            mylcd.lcd_display_string(
                "< "+CenterString[j:j+12]+" "*(12-len(CenterString[j:j+12]))+"  ", 2)
        else:  # between
            mylcd.lcd_display_string(
                "< "+CenterString[j:j+12]+" "*(12-len(CenterString[j:j+12]))+" >", 2)
        if(len(CenterString)-j <= 12):
            j = 0
        else:
            j += 1
        if(EncWatchPause(1-float(ScrollSpeed)/100)):
            return True
    if encoder.isClicked():
        AntiRebound()
    return True


# Let user navigate in a level of menu tree
def NavigateLevel(parentIdentifier, defaultIdentifier):
    parentData = menuTree[parentIdentifier].data
    subMenuIdentifiers = menuTree.is_branch(parentIdentifier)
    TotalData = []
    pos = 0
    for identifier in subMenuIdentifiers:
        TotalData.append(menuTree[identifier].data)
        if identifier == defaultIdentifier:
            pos = subMenuIdentifiers.index(identifier)
    if(parentIdentifier != "main"):
        TotalData.append([CenterOnScreen("RETOUR", 16), "", "c"])
    mylcd.lcd_clear()
    mylcd.lcd_display_string(CenterOnScreen(parentData[1], 16), 1)
    while(not encoder.isClicked()):
        led.setColor(TotalData[pos][2], led)
        encoder.updateCount()
        old_count = encoder.getCount()
        AutoScroll(TotalData[pos][0], pos, len(TotalData))
        while(not encoder.updateCount() and not encoder.isClicked()):
            pass
        encoder.updateCount()
        new_count = encoder.getCount()
        if(new_count > old_count and pos < (len(TotalData)-1)):
            pos += 1
        elif(new_count < old_count and pos > 0):
            pos -= 1
    AntiRebound()
    if(TotalData[pos][0] == CenterOnScreen("RETOUR", 16)):  # bring user back
        SelectionParent = ""
        for key in menuTree[parentIdentifier]._predecessor:
            SelectionParent = menuTree[parentIdentifier]._predecessor[key]
        print("BACK REQUEST to ", SelectionParent)
        return SelectionParent
    else:
        return subMenuIdentifiers[pos]


# Same as function above, but detached from menu tree
def NavigateInArray(line_1, array, defaultIndex, allowBack, led_color):
    if len(array) == 0:
        print("Can't navigate in empty array")
        return False
    if defaultIndex >= len(array):
        print("defaultIndex out of array")
        return False
    if allowBack:
        array.append(CenterOnScreen("RETOUR", 16))
    pos = defaultIndex
    mylcd.lcd_clear()
    mylcd.lcd_display_string(CenterOnScreen(line_1, 16), 1)
    setLedState(led_color)
    while(not encoder.isClicked()):
        encoder.updateCount()
        old_count = encoder.getCount()
        AutoScroll(array[pos], pos, len(array))
        while(not encoder.updateCount() and not encoder.isClicked()):
            pass
        encoder.updateCount()
        new_count = encoder.getCount()
        if(new_count > old_count and pos < (len(array)-1)):
            pos += 1
        elif(new_count < old_count and pos > 0):
            pos -= 1
    AntiRebound()
    if allowBack and pos == len(array)-1:
        return False
    return array[pos]


# Recursive function to navigate inside main menu
def Menu(firstParentIdentifier, defaultIdentifier):
    global ForceLevel
    global menuTree
    functions_needing_menu_update = [
        "show_attendance_controls", "control_delete"]
    while True:
        print("NAVIGATION INSIDE ", firstParentIdentifier)
        SelectionIdentifier = NavigateLevel(
            firstParentIdentifier, defaultIdentifier)
        if SelectionIdentifier in functions_needing_menu_update:
            update_menu()
        print("Selected identifier : ", SelectionIdentifier)
        SelectionData = menuTree[SelectionIdentifier].data
        # terminal level, we run requested action. Must implement data handling
        if(SelectionData[1] == ""):
            if "control_" in SelectionIdentifier:
                functionToCall = "control_" + \
                    SelectionIdentifier.split("_", 2)[2]
                argToPass = SelectionIdentifier.split("_", 2)[1]
                globals()[functionToCall](argToPass)
            else:
                # run function whose name corresponds to SelectionIdentifier
                globals()[SelectionIdentifier]()
            SelectionParent = ""
            for key in menuTree[SelectionIdentifier]._predecessor:
                SelectionParent = menuTree[SelectionIdentifier]._predecessor[key]
            if ForceLevel:
                firstParentIdentifier = ForceLevel[0]
                defaultIdentifier = ForceLevel[1]
                ForceLevel = []
            else:
                firstParentIdentifier = SelectionParent
                defaultIdentifier = SelectionIdentifier
        else:
            # NavigateLevel(SelectionIdentifier,0)
            firstParentIdentifier = SelectionIdentifier
            defaultIdentifier = 0

# FUNCTIONS ABOUT EXTERNAL DEVICES


def EncWatchPause(sec):  # Waits for action on encoder, with a timeout
    deb = datetime.datetime.now()
    while(datetime.datetime.now() < deb+datetime.timedelta(seconds=sec)):
        if(encoder.isClicked() or encoder.updateCount()):
            return True
        time.sleep(0.001)


def setLedState(state):  # Set let state (same as led.setColor but allows led shutdown)
    if state == "o":
        led.shutDown()
    else:
        led.setColor(state, led)


def AntiRebound():  # Avoid encoder button rebounds
    buzz.click()
    while encoder.isClicked():
        pass


def getUSBPath():  # Returns USB key mounting point
    key = USBKey()
    key.findUSBPath()
    return key.getPath()


def rtc_set_time(dt_to_write):  # Set Real Time Clock module time
    try:
        rtc.write_datetime(dt_to_write)
        # check update is good
        dt_read = rtc.read_datetime()
        if -2 < (dt_to_write - dt_read).total_seconds() < +2:
            print("datetime successfully update on RTC module : ",
                  dt_to_write.strftime('%Y-%m-%dT%H:%M:%SZ'))
            return True
        else:
            print("error while updating datetime to RTC, difference is too high")
            return False
    except ValueError:
        print("error while updating datetime to RTC, check wiring")
    finally:
        rtc.close()


def rtc_get_time():  # Read Real Time Clock module time
    try:
        dt = rtc.read_datetime()
        print("rtc time readed : ", dt.strftime(FileDatetimeFormat))
        return dt
    except ValueError:
        print("error with RTC chip, check wiring")
    finally:
        rtc.close()


def checkInternet():  # Checks internet connection using Google server
    url = 'http://www.google.com/'
    timeout = 5
    try:
        _ = requests.get(url, timeout=timeout)
        return True
    except requests.ConnectionError:
        print ("checkInternet failed : no Internet Connection")
    return False


def dismount_USB(mountpoint):  # Allows user to safely remove USB key from Raspberry
    # ASK USER IF REQUEST DISMOUNT AND SHOW HIM USB KEY NAME
    buzz.warn()
    chx = YesNoBackScreen("EJECTER CLE USB "+mountpoint.split("/")
                          [-1]+" ?", 'y', ['OUI', 'NON'], 'NON')
    if(chx == 'OUI'):
        os.system('sudo umount "'+mountpoint+'"')
        holdScreen(["DEMONTAGE CLE EN", "COURS PATIENTEZ"], 'y', 1, True)
        buzz.success()
        print ("USB Dismounted")
        holdScreen(['RETIREZ CLE EN', 'TOUTE SECURITE'], 'g', 2, True)

# AUXILIARY FUNCTIONS


# Interface that allows user to set a digit value with a certain pattern
def setDigit(line_1, line_2_pattern, digit_position, default, limit):
    mylcd.lcd_clear()
    mylcd.lcd_display_string(line_1, 1)
    mylcd.lcd_display_string(line_2_pattern, 2)
    pos = default
    while not encoder.isClicked():
        encoder.updateCount()
        old_count = encoder.getCount()
        while(not encoder.updateCount() and not encoder.isClicked()):
            # allows to blink pattern (perdiod of 2 seconds)
            if(datetime.datetime.now().second % 2 == 0):
                mylcd.lcd_display_string(
                    line_2_pattern[0:digit_position]+str(pos)+" "*(15-digit_position), 2)
            else:
                mylcd.lcd_display_string(
                    line_2_pattern[0:digit_position]+str(pos)+line_2_pattern[digit_position+1:16], 2)
            if EncWatchPause(0.8):
                break
        encoder.updateCount()
        new_count = encoder.getCount()
        if(new_count > old_count and pos < limit):
            pos += 1
        elif(new_count < old_count and pos > 0):
            pos -= 1
    AntiRebound()
    return pos


def Digit(nb, rank):  # Extracts a digit from number
    nb /= 10**rank
    return nb % 10


def Number(digits):  # Constructs a number from digits
    nb = 0
    i = 0
    for dig in digits:
        power = len(digits)-i-1
        nb += dig*10**power
        i += 1
    return nb
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

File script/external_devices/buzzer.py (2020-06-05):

#!/usr/bin/env python
import RPi.GPIO as GPIO
import time

"""
    This Class represents the Buzzer 
"""
class Buzzer():
    """
        Constructor
    """
    def __init__(self):
        self.buzzerPin = 22 #pin connected to the rpi
        self.enabled = True #is working or not 
        GPIO.setmode(GPIO.BCM)
        GPIO.setup(self.buzzerPin, GPIO.OUT)

    """
        This method is used to change the state of the buzzer 

        Argument : newState
    """
    def setEnable(self, _newState):
        self.enabled = _newState

    """
        This method is used to get the of the buzzer
    """
    def isEnabled(self):
        return self.enabled

    """
        This method is used to play a specified tone
    """
    def play(self,tones):
        if self.enabled:
            p = GPIO.PWM(self.buzzerPin, 440)
            for t in tones:
                p.ChangeFrequency(t[0])
                p.start(0.5)
                time.sleep(float(t[1])/1000)
                p.stop()
                time.sleep(float(t[2])/1000)

    """
        Play error tone
    """     
    def error(self):
        tonesList = [   #[frequency,duration,pause]
            [300,100,50],
            [200,300,0]
            ]
        self.play(tonesList)

    """
        Play success tone
    """    
    def success(self):
        tonesList = [   #[frequency,duration,pause]
            [200,50,50],
            [400,50,50],
            [600,200,0]
            ]
        self.play(tonesList)

    """
        Play disable tone
    """    
    def disable(self):
        tonesList = [   #[frequency,duration,pause]
            [600,50,50],
            [400,50,50],
            [200,200,0]
            ]
        self.play(tonesList)

    """
        Play click tone
    """    
    def click(self):
        tonesList = [   #[frequency,duration,pause]
            [500,30,50]
            ]
        self.play(tonesList)

    """
        Play warn tone
    """    
    def warn(self):
        tonesList = [   #[frequency,duration,pause]
            [500,50,50],
            [500,50,50],
            [500,50,50]
               ]
        self.play(tonesList)

    """
        Play start tone
    """    
    def start(self):
        tonesList = [   #[frequency,duration,pause]
            [100,200,50],
            [500,200,50],
            [700,300,50]
               ]
        self.play(tonesList)

    """
        Play shutdown tone
    """    
    def shutDown(self):
        tonesList = [   #[frequency,duration,pause]
            [700,200,50],
            [500,200,50],
            [100,300,50]
               ]
        self.play(tonesList)
    
    """
        play enable tone
    """    
    def buzzerEnable(self):
        tonesList = [   #[frequency,duration,pause]
            [100,50,50],
            [500,200,50]
               ]
        self.play(tonesList)

    """
        play disable tone
    """    
    def buzzerDisable(self):
        tonesList = [   #[frequency,duration,pause]
            [500,50,50],
            [100,200,50]
               ]
        self.play(tonesList)

if __name__ == '__main__':
    try:
        #try all melodies
        buzzer = Buzzer()
        buzzer.error()
        buzzer.success()
        buzzer.warn()
        buzzer.start()
        buzzer.shutDown()
        buzzer.buzzerEnable()
        buzzer.buzzerDisable()
    except:
        pass

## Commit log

2020-06-02 Clean history
    [07-01-2020-14-03-20.csv, 16x2_screens.xlsx, Encoder_cap.stl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]
2020-06-02 add electronic schematic
    [electronic_schematic.sch]
2020-06-02 update 3D Files
    [Fan_holder.stl, Lower_box.stl, Ports_hidder.stl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]
2020-06-07 added battery script
2021-10-23 enlarged utbm card tolerance
    [main.py]
2021-10-25 add print debug
2021-10-25 print full path
2021-10-25 update print error
2021-10-26 update led pin
2021-10-26 update fan service
